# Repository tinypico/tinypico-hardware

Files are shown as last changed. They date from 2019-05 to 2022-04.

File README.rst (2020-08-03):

TinyPICO Hardware
=================

In this repository you'll find Eagle 9.x design files and gerbers for the TinyPICO and any of the shields we design ourselves.

Gerber files are provided in 274X format.

As we release new shields and designed, we will add them here. 

Open Source License
-------------------

These files are released as open source under the CERN license. Please review the license before using these files in your own projects to understand your obligations.

TinyPICO Branding
-----------------
The name TinyPICO, logos and TinyPICO brand are owned by Unexpected Maker. If you would like to use the name in a project you are making that supports the TinyPICO hardware, please contact us and we'll be happy to talk to you about it.

Support Unexpected Maker
------------------------

We love designing, making and releasing our projects as open source. We do it because we believe it’s important to share knowledge and give back to the community as many have done before us. It helps us all learn and grow.

That said, a lot of time, effort and finances have gone into designing and releasing these files, so please consider supporting us by backing TinyPICO on our Crowd Supply campaign:

https://www.crowdsupply.com/unexpected-maker/tinypico

Or by buying one of our products on tindie or our own shop:

https://www.tindie.com/stores/seonr/
https://unexpectedmaker.com/shop

Or by becoming a Patron:

https://www.patreon.com/unexpectedmaker

Unexpected Maker
===================
http://youtube.com/c/unexpectedmaker

http://twitter.com/unexpectedmaker

https://www.facebook.com/unexpectedmaker/

https://www.instagram.com/unexpectedmaker/

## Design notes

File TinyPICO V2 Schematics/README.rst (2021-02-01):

TinyPICO V2 Schematics
======================

PDF schematics for TinyPICO V2 for both USB-C and Micro-B boards

Unexpected Maker
===================

http://unexpectedmaker.com

http://youtube.com/c/unexpectedmaker

http://twitter.com/unexpectedmaker

https://www.facebook.com/unexpectedmaker/

https://www.instagram.com/unexpectedmaker/

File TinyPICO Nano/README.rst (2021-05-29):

TinyPICO NANO Footprints
===============================

In this folder you'll find various ECAD versions of the TinyPICO NANO footprint that you can use on your PCBs.

EasyEDA footprint kindly provided by Brian Lough ( https://www.youtube.com/channel/UCezJOfu7OtqGzd5xrP3q6WA )
https://easyeda.com/component/a96b3b5613954f7abe1ca396b1f5ce27

**TinyPICO_Nano KiCAD files** - KiCAD 6 (v5.99) & v5 Footprints & Symbols kindly provided by Mark Olsson ( https://github.com/k0d )

**TinyPICO_Nano.Library.IntLib** - Altium foorprint kindly provided by Ketan Desai ( https://twitter.com/ketszim )

Diptrace ASCII files kindly provided by airheadbit

For more information about TinyPICO & TinyPICO NANO, please visit
https://www.tinypico.com/tinypico-nano

Open Source License
-------------------

These files are released as open source under the CERN license. Please review the license before using these files in your own projects to understand your obligations.

TinyPICO Branding
-----------------
The names TinyPICO, TinyPICO logos and TinyPICO brand are owned by Unexpected Maker. If you would like to use the name in a project you are making that supports the TinyPICO hardware, please contact us and we'll be happy to talk to you about it.

Unexpected Maker
===================

http://unexpectedmaker.com

http://youtube.com/c/unexpectedmaker

https://www.patreon.com/unexpectedmaker

http://twitter.com/unexpectedmaker

https://www.facebook.com/unexpectedmaker/

https://www.instagram.com/unexpectedmaker/

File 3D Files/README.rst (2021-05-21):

TinyPICO STL & STEP Files
==================

STL & STEP files for the TinyPICO family of boards

Right now I only have the TinyPICO USB-C version and the TinyPICO NANO versions up, but I'm working on the Micro-B version and will upload it soon.

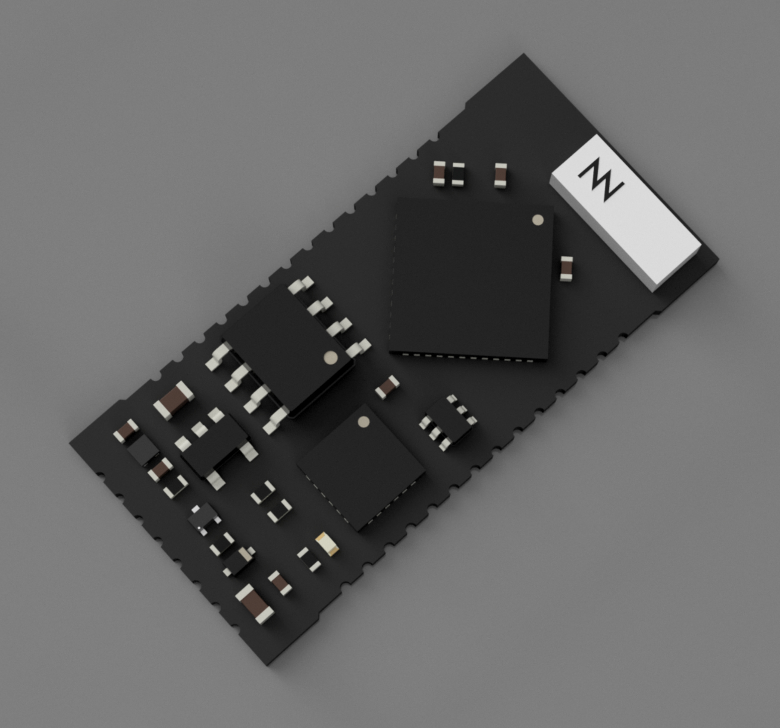
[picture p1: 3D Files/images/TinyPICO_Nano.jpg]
TinyPICO Nano STEP example


Unexpected Maker
===================

http://unexpectedmaker.com

http://youtube.com/c/unexpectedmaker

https://www.patreon.com/unexpectedmaker

http://twitter.com/unexpectedmaker

https://www.facebook.com/unexpectedmaker/

https://www.instagram.com/unexpectedmaker/

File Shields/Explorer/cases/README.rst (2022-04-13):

Explorer Shield 3D Cases
========================

In this repository you'll find the STL files for a slim and beefy case for your Explorer Shield

Support Unexpected Maker
------------------------

Please consider supporting me by purchasing one of my products on tindie or our own shop:

https://www.tindie.com/stores/seonr/
https://unexpectedmaker.com/shop

Or by becoming a Patron:

https://www.patreon.com/unexpectedmaker

Unexpected Maker
===================
http://youtube.com/c/unexpectedmaker

http://twitter.com/unexpectedmaker

https://www.facebook.com/unexpectedmaker/

https://www.instagram.com/unexpectedmaker/

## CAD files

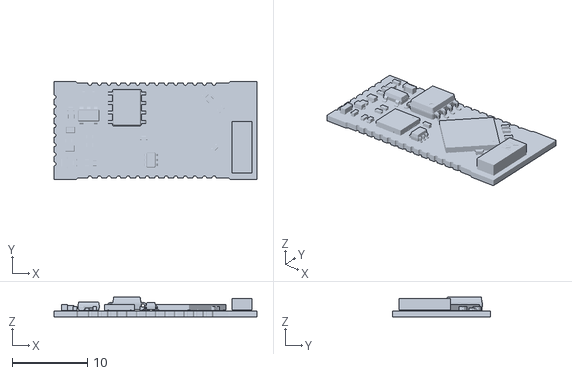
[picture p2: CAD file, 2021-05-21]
3D Files/TinyPICO Nano.stl
27.0 x 13.0 x 2.60

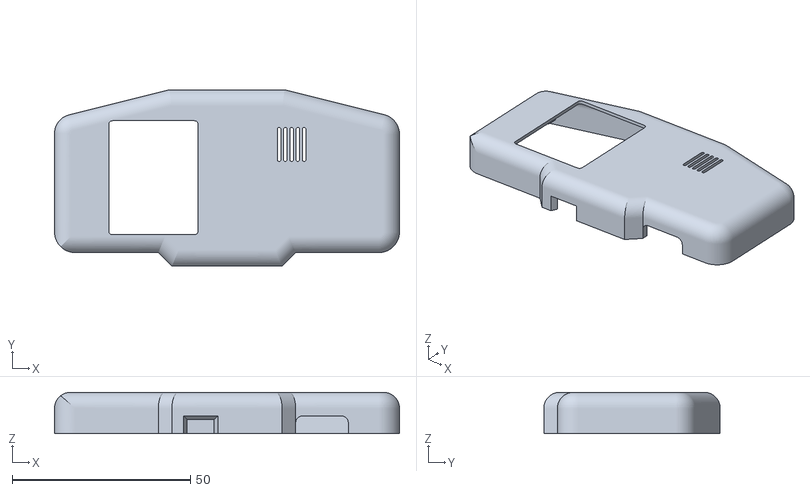
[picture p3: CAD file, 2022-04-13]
Shields/Explorer/cases/Explorer_Case_Slim.stl
96.7 x 49.5 x 11.6

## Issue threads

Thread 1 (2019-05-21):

Please consider maintaining "official" KiCAD footprint and symbol libaries.

sonopard, 2019-05-21:
Those things are needlessly hard to search for by with too many projects. Your chance to be better!

For now, I made this. https://github.com/sonopard/tinypico-kicad-footprint

UnexpectedMaker, 2019-05-24:
I don't use KiCAD so I won't be supplying footprints and design files, but I made the project is open source so others can contribute. So feel free to fork the project and submit pull requests for any KiCAD files you make and I can add them to the main repo.

Closed 2019-09-20.

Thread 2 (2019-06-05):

Eagle and Gerbers do not match

fcapano, 2019-06-05:
I've noticed some differences between the included gerber files and the Eagle project files.

For instance, the PSRAM' silkscreen is labeled "LY68L6400SLIT" in Eagle but simply "PSRAM" in the included gerbers.
Could you update the Eagle project so we are sure we're not missing any other more important change?

Thanks!

UnexpectedMaker, 2019-06-05:
Files have been updated, cheers.

Closed 2019-06-05.

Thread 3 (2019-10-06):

How are the values of L1, C4 and C5 decided?

dataplayer12, 2019-10-06:
Hi, I am wondering how you decided to use the values of L1 (7.5 nH), C4 (1.5 pF) and C5 (0.75 pF) for use with the antenna? The datasheet for the ESP32-Pico-D4, these values are different. Which value of these three would the performance be most sensitive to?

UnexpectedMaker, 2019-10-06:
The values on a matching network are specific to the exact board and layout its on. The values on the PicoKit are ONLY for the PicoKit - the values for the TinyPICO are ONLY for the TinyPICO.

Everything about the components on the board, their positions are orientations, the size of the board, number of layers, power and gnd copper pours, type of antenna, orientation of antenna, what other metal is near it.. it all changes the RF characteristics of the board.

The values on the TinyPICO are based on having it professionally matched by an RF expert.

Sounds like you need to do lots of reading up about RF and matching networks :)

dataplayer12, 2019-10-06:
Thanks a lot. I would really appreciate any pointers to reading material.

nevercast, 2019-10-07:
@dataplayer12 We do a bit of RF tuning at work, and what I have found is that, provided the antenna is 50ohms matched, you can usually put a 0ohm resistor across the series element (the series element on this particular board is C5, the element that is in series with the antenna line).

@UnexpectedMaker is correct that everything will change the performance of your antenna, and usually its best to tune it for its normal condition. For example, the TinyPICO probably spends most its time in a breadboard, so perhaps that would be the best situation to tune the antenna.

For your own board, it might usually be inside a chassis, and if its a handheld device, maybe it spends a lot of time in someones hands. So perhaps its best to tune it for that.

The fact is, your tuning will always be influenced by the environment and its not going to be perfect when its being used if that situation differs from when it was tuned in a lab. What advice I can give is that, if you're unable to follow recommended layout guidlines set out by the antenna you're using (such as shape and size of copper fills, and the proximity to other components), you might want to consider getting it tuned. If however, you have a very short trace from antenna port on the ESP32 to antenna on your board, you're probably fine putting a 0ohm series element in there, since the antenna should be already pretty close to tuned.

If you find the need to properly tune your antenna then I suggest buying a VNA, since unless you have a friend that will do the tuning for free, hiring an RF engineer with the equipment can be very experience. We use a miniVNA at my place of work and it does the job.

One extra point, when tuning, we usually put the tuned frequency at the left hand side -3dB point, so that the tuned frequency is slightly higher than ideal. That's because we suspect the device to be loaded by its surroundings and that will pull the frequency down to its ideal point.

I'd be happy to discuss this sometime if you want more information, find me on Twitter https://twitter.com/NvrCast

dataplayer12, 2019-10-07:
Thanks. Your explanation is very helpful. That explains why in some boards, people have left out the values of parallel elements. There may be no need to use them for most applications. I am curious as to why a 0 ohm series element is necessary. After all it is 0 ohm and as far as I understand, electrically it does nothing.

UnexpectedMaker, 2019-10-07:
The 0 ohm bridges he pads... otherwise there is a short between the ESP32 and the Antenna

dataplayer12, 2019-10-07:
Yes, I understand that, but could you not eliminate this part entirely and just have a wire in place of the pads.

nevercast, 2019-10-07:
> and as far as I understand, electrically it does nothing.
Correct. As @UnexpectedMaker pointed out, without briding the gap, the antenna and ESP32 are not connected. So you place a 0Ohm component in what would be C5 for the TinyPICO and that at least connects the Antenna to the ESP32 antenna port.

UnexpectedMaker, 2019-10-07:
Sure, you could just put a trace instead of the pads, but then how do you tune it with parts? The pads are there so you (if you get the expertise) or someone else can tune it... if you don't care about good quality RF, or even more, if you don't care that the implementation of your antenna could be reflecting, causing unwanted heat and power drain, then sure.. don't put any matching network, and just stick an antenna on there :)

UnexpectedMaker, 2019-10-07:
Unfortunately, RF is complicated, and it's not a "one size fits all" - every board design that implements an antenna should be tested to *at least* ensure the board is performant and doesn't have adverse effects from heat or power.

Ultimately, if you are making a hobby project for yourself, and putting an antenna on your board gives you the wifi quality you need, you can avoid getting it matched.., but if you are making something for others to use, then a properly matched network is the right thing to do.

dataplayer12, 2019-10-07:
Your advice makes a lot of sense. Since this is my first board, I will not tune it and see how it works. Thanks, you have been a great help!

niemeyer, 2021-02-06:
Here we are in 2021, on a Saturday, and this is still an interesting thread. Kudos to all commenters.

Montvydas, 2021-04-25:
I know the issue was closed, but since the TinyPico changed the RF design slightly, I was wondering, why was the matching network removed from V2 design completely as can be seen [here](https://github.com/tinypico/tinypico-hardware/blob/master/TinyPICO%20V2%20Schematics/TinyPICO_V2_C2_Schematic.pdf)? This surprised me since the previous design later added an identical 3D antenna, thus I was expecting to see a similar matching system..

matt-42, 2022-01-07:
> I know the issue was closed, but since the TinyPico changed the RF design slightly, I was wondering, why was the matching network removed from V2 design completely as can be seen [here](https://github.com/tinypico/tinypico-hardware/blob/master/TinyPICO%20V2%20Schematics/TinyPICO_V2_C2_Schematic.pdf)? This surprised me since the previous design later added an identical 3D antenna, thus I was expecting to see a similar matching system..
>
> Edit: So it seems the matching network should be removed if the transmission line length is smaller than 5mm (1/10 of wavelength), I guess that might be the case then on V2...

That would be great where did you find this info? I found another ESP32 board without matching circuit: https://github.com/TobleMiner/ESP32-Devkit-Type-C/issues/3

Montvydas, 2022-01-13:
> That would be great where did you find this info? I found another ESP32 board without matching circuit: [TobleMiner/ESP32-Devkit-Type-C#3](https://github.com/TobleMiner/ESP32-Devkit-Type-C/issues/3)

Well, the bits of information are scattered there and there, but if you watch [this talk](https://www.youtube.com/watch?v=ZYUYOXmo9UU), or at least the bit starting at 38:30, it talks about when to care about the line lengths. In the video they used 1/12 of the wavelength, which is more precise, but 1/10 is easier to calculte, that's why it's usually used... So a rule of thumb! Basically a typical PCB dielectric (FR-4) has a relative permittivity of ~4.5. If  it's an inner layer trace, then the refractive index is 2.12 (square root of permittivity). On the outer layer, it is a combination of both air and the PCB dielectric, thus the relative permittivity of ~3.5, then the refractive index is 1.87. Thus, depending on the scenario the velocity drops by a factor of 2.12 (inner) / 1.87 (outer), which changes the wavelength of the 2.45GHz signal to 57.7mm / 65.5mm (wavelength = speed / freq). 1/12th of that is 4.8mm / 5.45mm, meaning if the transmission line is longer than that, then a matched network needs to be added. This is theoretical though, since any components on the board and the added device case (even if made of plastic) will affect the antenna and thus it will require rematching.. However with a case on is added the BLE will still work, it will simply add losses and thus battery will be drained somewhat faster if you want to keep the same signal strength.

Anyway, an easy thing to do is to add a pi-network with a 10pF capacitor shorting the MCU and the antenna. At 2.45GHz 10pF is somewhat close to 0 Ohm impedance and thus it will not change anything. However if you later decide that you want you device matched you can send it to a specialised service and they will decide what the pi-network components should be. Note that a 0 Ohm resistor will not work as 0 Ohm impedance at 2.45 GHz, since it has inductance, thus better use the 10pF capacitor (it is worth checking manufacturer graphs for their capacitors as they got impedance vs frequency graphs for various capacitor sizes and packages.. thus helping to decide for the best value, just 10pF is usually somewhat OK). Hope that helped!

Montvydas, 2022-01-14:
Regarding TobleMiner/ESP32-Devkit-Type-C#3, if you use a PCB antenna, then you can avoid using a matching network by firstly making the antenna tail longer than needing. Then during the matching process you can cut the tail bit-by-bit until you establish a matched network. This type of process changes the antenna built-in impedance (combination of capacitance and inductance) by physically altering the antenna rather than introducing extra components. That's one of the benefits for using a PCB antenna in this case, but you would still need a VNA (or can get a nanoVNA for under £50 on Aliexpress). I think I learnt this from Robert Feranec video, where they discussed antennas, but cannot be 100% sure now, it was some time ago now...

matt-42, 2022-02-08:
Thanks @Montvydas for all the explanations :)

Closed 2019-10-07.

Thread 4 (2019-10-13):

Gerbers_274X TinyPICO.sol

SZ-MXK, 2019-10-13:
Hi,
The Gerbers file is wrong.

UnexpectedMaker, 2019-10-13:
Sorry, but the gerber is correct. These are the production gerbers that I shipped thousands of boards with.

Closed 2019-10-13.

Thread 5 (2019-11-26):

how much current will the gpio35 draw?

dukeduck1984, 2019-11-26:
when the battery voltage ADC is not in use, how much current, if any, will the gpio35 draw?

Thanks,
Kaiyuan

nevercast, 2019-11-26:
GPIO35 is an input only pin and has no hardware drivers. Therefore the pins should follow nominal leakage characteristics when not being sampled. Therefore I would expect 50nA according to the input current specified here: https://www.espressif.com/sites/default/files/documentation/esp32_datasheet_en.pdf#page=41 and here https://www.espressif.com/sites/default/files/documentation/esp32-pico-d4_datasheet_en.pdf#page=15

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

nevercast, 2019-11-26:
Looking at the schematic https://github.com/tinypico/tinypico-hardware/blob/master/TinyPICO%20Release%20P3/TinyPICO_Schematic.pdf

The divider is always enabled when on battery and sends the battery to ground through about 600kOhm which is about 6 microamps at 3.7V. You can probably increase the resistor values and keep their ratio if 6 microamps is too much for you.

UnexpectedMaker, 2019-11-26:
The divider is always on when the board is powered, even if no battery is present, as the PMIC can't tell the different between no battery and a full battery, so still tries to charge, so VBAT always has voltage, so the divider is always sucking current.

But as Josh pointed out it's low uA... I'd not increase the resistors unless you don't want to be able to read the voltage accurately, as higher value resistors will just increase their susceptibility to noise, decreasing the ADC's accuracy.

So if you don't need to read the voltage, removing one of the divider resistors means no current use at all, but if you do want to read the voltage, ultimately, it's not costing much.

The TinyPICO deep sleeps at 18uA or less.

Closed 2020-03-17.

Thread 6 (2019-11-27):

Add ov2460 camera

dontsovcmc, 2019-11-27:
Thanks a lot for you tiny board!
It's what I need. How do you think, is it hard to add ov2460 2MP camera module to the board? ESP32-CAM board is rather popular, but isn't power safety and big. I can help, if possible.

UnexpectedMaker, 2020-03-17:
Feel free to make an OV2460 shield for the TinyPICO and contribute it back to the project, as it is open source after all.

Closed 2020-03-17.

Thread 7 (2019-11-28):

Where can I download a 3D Model?

Pro, 2019-11-28:
We would need the 3D Model of the TinyPico for building a Case and visualizing the board on it.

Could you add the model to the git repo (in the ideal case as STEP file)? Or is it available somewhere else?

UnexpectedMaker, 2019-11-28:
Sorry, there is no 3D model for the TinyPICO.

Seon Rozenblum | Unexpected Maker
http://unexpectedmaker.com <http://unexpectedmaker.com/>

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

Pro, 2019-11-28:
Bad news, but thanks anyways!

taf2, 2021-12-15:
I found this one which is pretty good https://grabcad.com/library/tinypico-esp32-1  it is an older model but I've been using it with some success

UnexpectedMaker, 2021-12-15:
Official models are all available here.... :)
https://github.com/tinypico/tinypico-hardware/tree/master/3D%20Files

Closed 2019-11-28.

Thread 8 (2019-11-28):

External 5V Power supply and USB 5V at the same time?

Pro, 2019-11-28:
I have a setup where the 5V Pin is connected to an external power supply.

My question:
Is it safe to plug in the USB Cable with its own 5V Power Supply while there's still 5V coming through the 5V Pin?

Use Case is that I need to re-flash it while the external power supply is on, or I want to open the monitoring through USB.

Thanks!

Pro, 2019-11-28:
I already checked the board itself and saw that the 5V goes to a Chip with labeling "65b902". I couldn't find out which chip it is.

UnexpectedMaker, 2019-11-28:
No, there is no reverse USB protection, so you may backfeed power and damage your host USB port. Only way is to ensure the power going into the 5V pin is lower than the 5V from the USB, but even then, its not recommended.

Also, this repo is not for TinyPICO support, sorry...  Please join my discord server for support Q's.
https://discord.gg/xAHpApP

Thanks.

Pro, 2019-11-28:
Ok, sorry for spamming here. Will use the Discord Server! Thanks anyway for answering!

Closed 2019-11-28.

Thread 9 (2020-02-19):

Low-Battery / Over discharge

CrispinP, 2020-02-19:
What stops over discharge of the battery?

I can't see anything in the schematic that would handle this.

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
The ESP can operate down to 2.2V. With the LDO drop of 190mV that would pull the battery down to 2.3/2.4V before it would get flaky. A bit low for a li-ion battery.

Have I missed something?

nevercast, 2020-02-19:
For what it's worth, the ESP32-PICO can only work down to 2.7V due to the internal flash being a 3v3 device. You will get flash errors lower than 2.7V

UnexpectedMaker, 2020-02-19:
Yup, you need to use protected LiPos. The ones with the yellow on the top.
This really isn't a TinyPICO github issue, and is more a question for Discord :)

CrispinP, 2020-02-19:
ah ok. Thanks.
So I'm not reading it wrong.

(Agreed on the last point 😄 )

Closed 2020-02-19.

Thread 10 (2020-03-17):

Req: Missing part libraries

henrygab, 2020-03-17:
Just found and picked up my first TinyPICO ... very impressive form factor.

I went ahead and loaded the board & schematics in Fusion 360 (which now has the functionality of Eagle built-in).  The problem is, many of the parts used reference libraries that are not public.

Could you please do one of the following two things?

1. make the following libraries, which contain parts used by the TinyPICO, available in the git repo?
  * cmonr_standardparts
  * CP2104
  * microbuilder
  * NCP170AMX300TCG
  * Philbywhizz
  * supply1
  * UnexpectedMaker

2. Alternatively, can you put all the parts used for this board into a single library, and make it a "managed" library in Eagle? This would allow it to be downloaded automatically by Eagle / Fusion360 users, including getting updates if anything changes.

Having the libraries for the parts is the first step to enabling full 3D models in Fusion360.  Having the 3D model makes it **_really_** easy for makers to create custom enclosures, using any output supported by Fusion360 (e.g., 3D-printing, laser-cut acrylic, CNC, etc.).  The 3D model it makes is already really good, but it can't show the usb connector, and the boxes are wrong-sized for other parts.  Still, it's already really close!

The only remaining step then would be to ensure the parts have the 3D models ... which is itself a zero-cost service (for end users).  Mouser, for example, has some relationship with [LibraryLoader](https://www.samacsys.com/library-loader-help/), and they turnaround simple new requests (e.g., common chip packages) in ~48 hours.

Thanks!

UnexpectedMaker, 2020-03-17:
Hi Henry,

I didn't supply a TinyPICO library because it's really not needed due to the way Eagle works.

All of the data you need for each part on the board is in the board file, so you can easily and quickly make your own library of the parts of you want to go down the road of attaching 3D models to the components.

Create a library, open it in the editor, and then right click on the parts you want to add, and copy the device to the library. From there, you can assign 3D models if you choose.

As the project is open source, what you are asking for seems like a perfect candidate for what you (or others could make) and then contribute back to the project :)

Cheers,
Seon

henrygab, 2020-03-18:
Hi @UnexpectedMaker ,

Thanks for the quick response.  I am willing to do this, and submit a PR.  The steps for doing this are not obvious.

<details><summary>Parts list context menu fails...</summary><P>

However, I'm not entirely clear how to copy a device that has no backing library from and existing brd/sch pair.

My steps to try:
1. Create new user library
2. Open the TinyPICO.sch schematic in Eagle
3. Select `Design Manager` super-tab
4. Select `Browser` to see the parts list
5. Click on header `Device` to sort by device name
6. Right-click on part `IC2G$1`, the CP2104 USB-to-Serial chip
  a. Clicking `Package` results in error: `Part 'IC2G$1' not found!`
  b. Clicking either `Open Symbol` or `Open Device` results in error: `Library CP2104.lbr was not found in current library path(s). Please adjust the library paths or download or export the drawing libraries first!`

</details>
<details><summary>Export?</summary><P>

I am now trying File->Export, to dump all the parts used into a new library.  This seems to generate a large script, and runs the script to add parts to the new library ... with all the performance that suggests.  I'm waiting for this to finish.
</details>

Is this export option the start of the path you were suggesting, or did you have another alternative in mind?  I couldn't find a way to just right-click on a part to be able to add it to a new library....

UnexpectedMaker, 2020-03-18:
1. Create and open a new library.
2. Import & open TinyPICO schematic
3. Right click on a symbol in the actual schematic
3. Select "Copy device to library" - will be greyed out if the library is not open.
4. Repeat for all components, then save the library.
5. Win!

This is the Eagle workflow that also works in Fusion360

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

henrygab, 2020-03-18:
Awesome!  Thanks for the pointers.  I'll see what I can put together!

henrygab, 2020-03-18:
Update:  Any efficient use of Eagle appears beyond my ken.  I've either given up, or put this on a backburner for now.

Closed 2020-03-18.

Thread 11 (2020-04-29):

Schematic for RGB IPS Display Shield

patfelst, 2020-04-29:
Hi Seon, is it possible to publish the schematic for your RGB IPS Display Shield please?

Thanks!

mcauser, 2020-06-25:
Hi @patfelst I don't have the schematics, but I know the pinout:

|TinyPICO|IPS Display|
|-|-|
|n/c|MISO|
|GPIO23|MOSI|
|GPIO18|SCLK|
|GPIO5|CS|
|GPIO15|DC|
|GPIO14|Backlight|
|n/c|RST|
|3V3|VCC|
|GND|GND|

No MISO means you can only write data to the display, you can't read any data back.

UnexpectedMaker, 2020-06-25:
Thanks for the push @patfelst ;)
https://github.com/tinypico/tinypico-hardware/tree/master/Shields/IPS%20Colour%20Display

patfelst, 2020-06-25:
Thanks again

Closed 2020-06-25.

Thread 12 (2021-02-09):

No schematic for the tinypico nano

Leviathan220, 2021-02-09:
I am trying to design a board in kicad using the tiny pico nano. I have installed the kicad footprint but, where is the schematic. I can make one from scratch using the pdf if I need to. Please let me know if you would like and I will attach a copy unless you have one I can use.

UnexpectedMaker, 2021-02-16:
KiCAD Symbol has been added, cheers :)

Closed 2021-02-16.

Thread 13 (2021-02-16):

Honored but not sure if it was an accident.

Leviathan220, 2021-02-16:
I hopped on today to download the kicad symbol. I haven't tried it yet however, when going to download the files I noticed I had permission to edit the repo. I figured I would bring it to your attention as I wasn't sure if you did so on accident. I'm still waiting on my recent order to arrive but, I'm honored you'd trust me with permissions to your repo.

nevercast, 2021-03-20:
Your user doesn't say contributor or maintainer. Are you sure you have writes to modify this repo and it's not GitHub abstracting away a fork of this repo ?

Closed 2021-07-16.

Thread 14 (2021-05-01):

STL files

Death111, 2021-05-01:
Hey,
I wanted to download TinyPICO_V2_USBC STL files https://github.com/tinypico/tinypico-hardware/tree/master/STL%20Files but only .step file is available. Do you also have STL files?

I want to use it as reference for 3d modeling case and to not have a tool supporting .step files.

Thanks
Death

UnexpectedMaker, 2021-05-14:
Once I `finally` get the step modules finished, I'll see if I can export STL's as well.

Death111, 2021-06-12:
I notice you were able to export the STL's :) Thanks @UnexpectedMaker

~ https://github.com/tinypico/tinypico-hardware/tree/master/3D%20Files

Closed 2021-06-12.

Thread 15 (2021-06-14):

C23 is a duplicate of C1?

FreezeS, 2021-06-14:
Hi Seon,

I believe this was accidental but if you did it on purpose then what's the purpose?
Is the capacitance/inductance of the wire between the reset button and the reset pin so high that it needs two capacitors?

UnexpectedMaker, 2021-06-14:
It’s not accidental. Both caps were included on purpose. C23 sits at the auto reset circuit.

Closed 2021-07-11.

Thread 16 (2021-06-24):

tinypico board layout

bilaljo, 2021-06-24:
I would like change out the prog resistor R3 against another (to change the battery current properly for my LiPo). Since I have only the schematic (and real board) it is hard to figure out which one is the correct one. I could only guess, which is quite unsafe.
Could you push an layout file of tiny pico (nano) as well?
Thanks.

UnexpectedMaker, 2021-06-24:
Sorry, which board are you asking about the VBAT Prog resistor for? The TinyPICO or the TinyPICO Nano?

bilaljo, 2021-06-24:
Sorry vergot to mention. The TinyPICO Nano.

UnexpectedMaker, 2021-06-24:
I've highlighted the resistor with a blue outline.

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

bilaljo, 2021-06-24:
Great, that's what I was searching for! Thank you very much.

UnexpectedMaker, 2021-06-24:
Nps!

Closed 2021-06-24.

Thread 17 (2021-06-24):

Casing of R3 PROG (Tiny PICO Nano)

bilaljo, 2021-06-24:
Has the casing of R3 PROG Resistor from Tiny PICO Nano a 0402 casing? The size looks so.

UnexpectedMaker, 2021-06-24:
Yes, it's an 0402 3.3K resistor.

bilaljo, 2021-06-24:
Thank you!

Closed 2021-06-24.

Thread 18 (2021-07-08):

Other I2C pin than IO21 and IO22

bilaljo, 2021-07-08:
It is possible to use other pin than IO21 and IO22 for I2C? They are marked as I2C pins on the tinpy pico pinout which makes me quite unsure.

UnexpectedMaker, 2021-07-08:
You can initialise I2C with any pins, but 21,22 will give you hardware I2C, where other pins will be software I2C.

bilaljo, 2021-07-08:
Thank you for your answer. Is that a tiny pico specific feature? Since I found this post on the esp32 forum:

"Yes, the digital portion has two hardware I2C modules. You don't see the pins for it in the pinout because they're conencted to the GPIO mux and you can connect them to any of the (output-capable) GPIOs."

https://esp32.com/viewtopic.php?t=215

UnexpectedMaker, 2021-07-08:
TinyPICO is an ESP32 and can do whatever an ESP32 can do. Some pins will give you hardware, some software I2C depending on which you use.

The ESP32-PICO-D4 datasheet is the best place to look.

Closed 2021-07-16.

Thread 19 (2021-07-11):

Sensing when USB power is present on V1 boards

Paraphraser, 2021-07-11:
I have some TinyPico V1 but an application where they will mostly be getting power via USB but I would like to be able to sense when USB power goes away and the battery takes over.

In comparing the V1 P3 and V2 C2 schematics, it looks like the V1 boards can't do that. True? Or am I misreading the purpose of GPIO9? Is there a workaround?

I'm happy to order some V2 if need be. I just didn't want to do it unnecessarily.

UnexpectedMaker, 2021-07-11:
That's correct. V1 doesn't have this capability on board. It's a V2 only feature. You can add this yourself by connecting a voltage divider between the 5V pin and GND and connecting the middle of it to an IO on the TP and reading if it is high or low.

Closed 2021-07-16.

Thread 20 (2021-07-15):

Unable to flash tiny pico nano

bilaljo, 2021-07-15:
Is there anything to consider when flashing a self-designed board with a tiny pico nano?
I am using a micro usb B as port and UART is working fine (since I am able to see the tiny pico nano as listed device) but I got always the error
"esp32 invalid head of packet"
I know thats for esp32 a well-known issue but all suggested solutions do not working (especially because they are only for pre-builded boards).

UnexpectedMaker, 2021-07-15:
Do you have anything connected to IO0, IO2, IO5 or IO12?
Can you share your schematic with me? You can email it to me if you don't want to post it here publicly.

All Nanos go through the testing twice. Once before being cleaned and once again after being cleaned, so all boards have successfully been flashed 2 times with MP and have had all of the tests run on them twice.

bilaljo, 2021-07-16:
Yes, I have IO12 connected to a device.

UnexpectedMaker, 2021-07-16:
IO12 is a strapping pin.  It needs to be untouched at boot, or at best, never pulled high during boot.
Check the PICO-D4 Datasheet for all scraping pins and what you can and can't do with them during boot up.

bilaljo, 2021-07-16:
Thank you very much. In fact it was a socket for a battery so only connecting + and - (without battery) while flashing solved it.
Oh I see I meant actually IO2 but I think same problem with IO2, right?

UnexpectedMaker, 2021-07-16:
Why are you connecting a battery to IO2? Never connect a power source to an IO pin.

bilaljo, 2021-07-16:
For watching the battery level since it has an ADC.
Oh is that a serious problem?

UnexpectedMaker, 2021-07-16:
So long as it’s going through a voltage divider it’s ok.

You should have nothing connected to any strapping pins at all that influence the state of them at boot time.

None of this is TinyPICO Nano related, so I’m going to close this as it’s not an issue.

Feel free to join my discord to ask questions there.

Closed 2021-07-16.

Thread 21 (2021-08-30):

Charging current resistor hint correction

Techspiring, 2021-08-30:
Hey mate,

I'm currently supporting a friend using the tiny pico.
The TPS4065 you're using is designed for charge-currents of 3 .. 600mA.
Charging at 1.000mA is not working properly, so the hint for the 1k0-Resistor in the schematic is a bit off.

Here is the product page if you want to check.
http://www.tp-asic.com/te_product_a/2009-05-20/2636.chtml

All the best :)

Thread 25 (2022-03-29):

Which contact is GPIO13?

CluckCluckChicken, 2022-03-29:
GPIO13 is used to toggle on/off the DotStar LED, but I need to use it for something else (it is HSPI MOSI and I have a screen that I want to run at a higher refresh rate). Where is the contact on the board so that I can desolder whatever is there and solder on something of my own?

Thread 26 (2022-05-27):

tinypico not upload program using platformio with micro USB

waqas-subhani, 2022-05-27:
kindly help, if anyone of can. thanks

A fatal error occurred: Failed to connect to ESP32: Wrong boot mode detected (0x13)! The chip needs to be in download mode.
For troubleshooting steps visit: https://docs.espressif.com/projects/esptool/en/latest/troubleshooting.html
*** [upload] Error 2

UnexpectedMaker, 2022-05-27:
Sorry, not the place to ask this - It sounds like a platformIO configuration issue. Please try my discord server, or the platformIO community.

Closed 2022-05-27.

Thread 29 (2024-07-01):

PCB Dimensions for footprint and Shield Ground

JL1946, 2024-07-01:
Hello...
I am making a Kicad footprint for the TinyPICO P3 Board... I am using the tinypico/tinypico-hardware/TinyPICO Release P3/Eagle/TinyPICO.brd to make the measurements using the built-in Kicad measuring tool... With the board placed such that the long-side is in the  y-direction and the short side in the x direction, the distance between the each pad in the y-direction is the standard 2.54 mm or .1 in... However, in the X direction I am measuring 15.2654 mm or 0.601 in between the pads (center-to-center)... Is this correct??? As for the size of the board (less critical), I am measuring the y-direction as 31.852 mm or 1.254 in. and 17.780 mm or  0.7 in.  Are these measurements in the ball-park???

I have included some jpg photos to show the orientation of the footprint...

One last thing... From the schematic, I saw that you tied the shield of the USB-C connector to the power/signal ground... I am incorporating your board onto another board which implements a separate trace for Earth-Ground which the usb-c cable shield routes to an Earth connection at the power supply... The design is using TVS diodes to transfer any ESD picked up by the sensors of the system to that Earth-Ground path... However, with Shield tied to the signal/power ground, it seems to me that any ESD would be routed to that ground as well... What is your opinion on this issue? Thanks for your timely response on the issues that I have outlined in this writeup...
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

UnexpectedMaker, 2024-07-01:
I guess all that really matters here is to have 32x18mm clearance for the board (maybe longer to ensure antenna clearance from other components on your carrier board) and the headers are 17.78m apart (7x 2.54mm header pin spacing).

With regards to the USB shielding being connected to GND, I'm not really sure how you have all of that connected as you mention another USB-Connector connected to your power supply?

Even without the TinyPICO USB Shield connected to the TinyPICO GND, you still have GND connected via the TP USB-C connector through the wires, so that is already going to connect to your "Earth GND" if you have them common - and I'm. not sure how it would work if they were not common - technically both could be the same value, but technically they could be quite different, and then you'd mess with the voltage rails on the TinyPICO.

I think what you need to do, is if you are connecting USB to the TinyPICO (I assume for flashing etc, but other times the power will come from your other supply?) then you should use a modified USB-C connector that has GND and maybe 5V cut so it only provides D+/D-.

The USB-C shield -> GND part really makes no difference here as You are connecting USB-C->GND anyway.

Without seeing your intended schematic or having a thorough understanding of what you are doing I can't really advise any best practice here, sorry.

JL1946, 2024-07-05:
Hi...
Thank you for your response... Please clear this up for me... I measured the distance between the headers to be 6 x 2.54 mm = 15.24 mm, not 7 x 2.54 = 17.78 mm... I measured the board width to be 17.78 mm which would make sense if you list the pcb as 18mm x 32mm...

Sorry to hound you, but I live in Canada and am ordering the TinyPICO V3 from the USA... My pcb's are being made in China... I don't want to make a mistake... thanks for understanding...

UnexpectedMaker, 2024-07-05:
Sorry, I don't understand the question, you don't measure between the headers, you measure from header to header, The headers are 17.78mm apart.

How much space you have between them is not a measurement I can give you, as it depend on how you mount the board to your carrier., What type of headers you use. Surface mount headers on your carrier will take more space then through hole.

JL1946, 2024-07-06:
I have included 3 photos to try to clarify my issue... The first is a picture of your board I want to use... the second is a jpeg of the motherboard I designed that shows the footprint placement of the TinyPICO P3 board that I want to buy from you... The third is a jpeg of the Top Copper Layer or TinyPICO.cmp file from your Github/.../TinyPICO Release P3/Gerbers_274X directory... This jpeg shows 3 pads marked "A", "B", and "C"... According to the Gerber Viewer that I am using, The x-y positions of the pads in mm (relative to 0,0 axis) are as follows:
"A" --> x:4.8885  y: 21.3444
"B" --> x:7.4285   y: 21.3444
"C" --> x:4.8885  y: 6.0790

When I do the math, I get the distance between Pads "A" and "B" to be 2.54 mm... The distance between Pads "A" and "C" to be 15.2654 mm which is very close to 6 times 2.54, NOT 7 times 2.54... The Gerber viewer I'm using can't be wrong or, otherwise the calculated distance between Pads "A" and "B" would be wrong...

I want to have my board manufactured but don't want to make a mistake and waste time and money... I hope that this clarifies the issue I'm having...

Also, If I purchase from your website:
( https://unexpectedmaker.com/shop.html#!/TinyPICO/p/577111313/category=154494282 ) Do you ship to Canada?

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

UnexpectedMaker, 2024-07-06:
Sorry, I miss understood what you were asking originally.

Here are the dimensions in an easy to understand way:
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

Yes, I ship all over the world from my website :)

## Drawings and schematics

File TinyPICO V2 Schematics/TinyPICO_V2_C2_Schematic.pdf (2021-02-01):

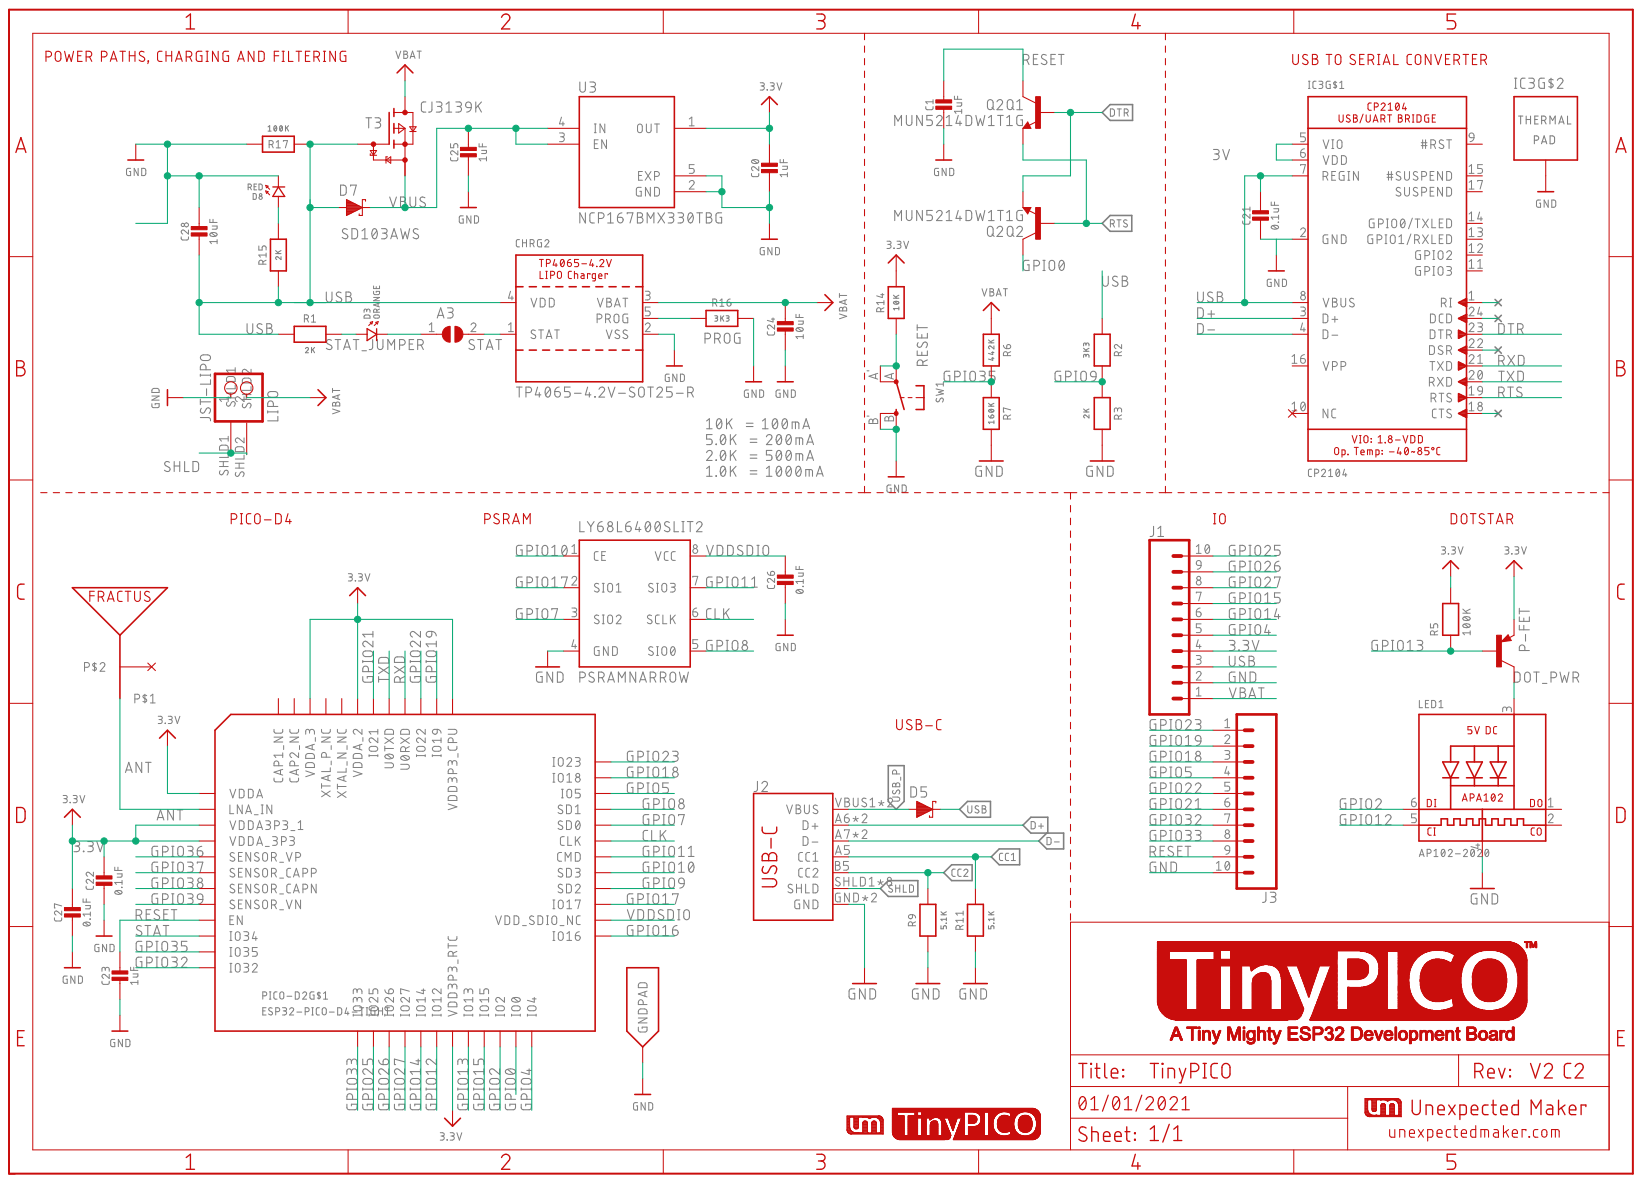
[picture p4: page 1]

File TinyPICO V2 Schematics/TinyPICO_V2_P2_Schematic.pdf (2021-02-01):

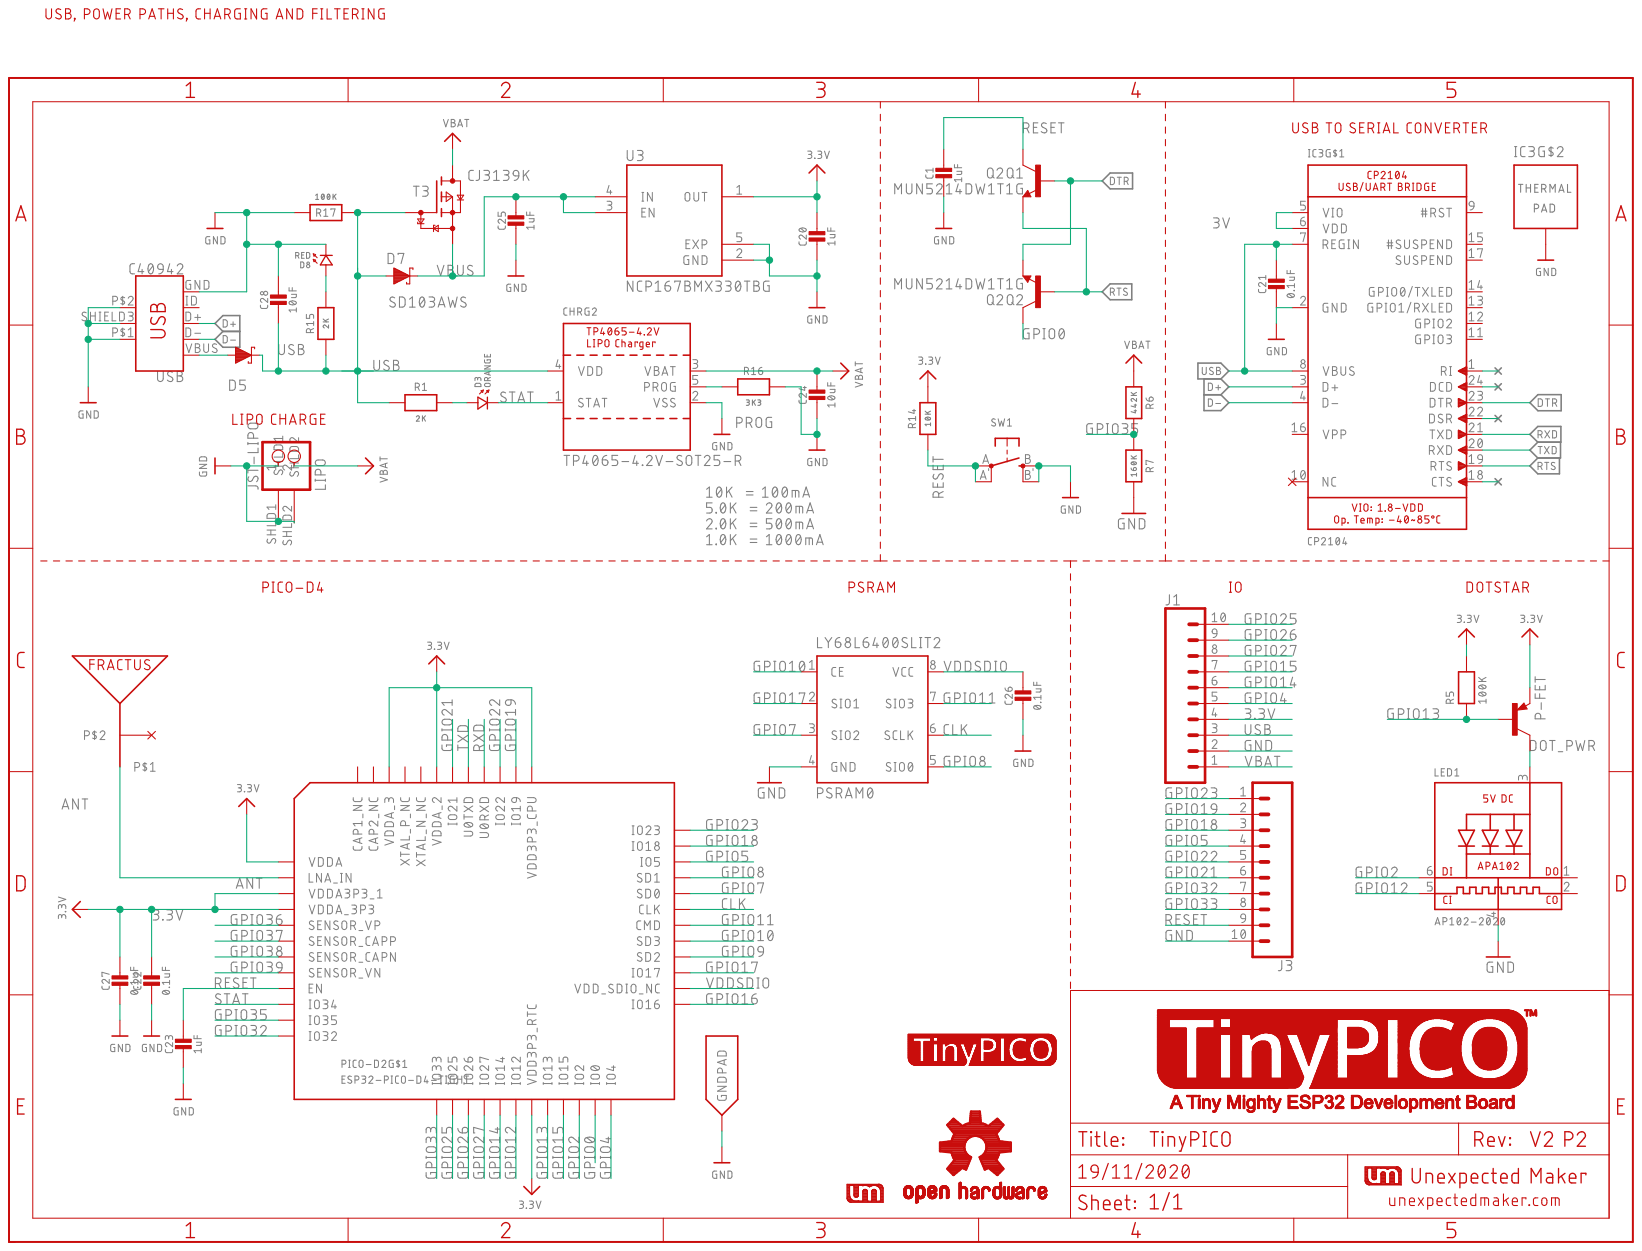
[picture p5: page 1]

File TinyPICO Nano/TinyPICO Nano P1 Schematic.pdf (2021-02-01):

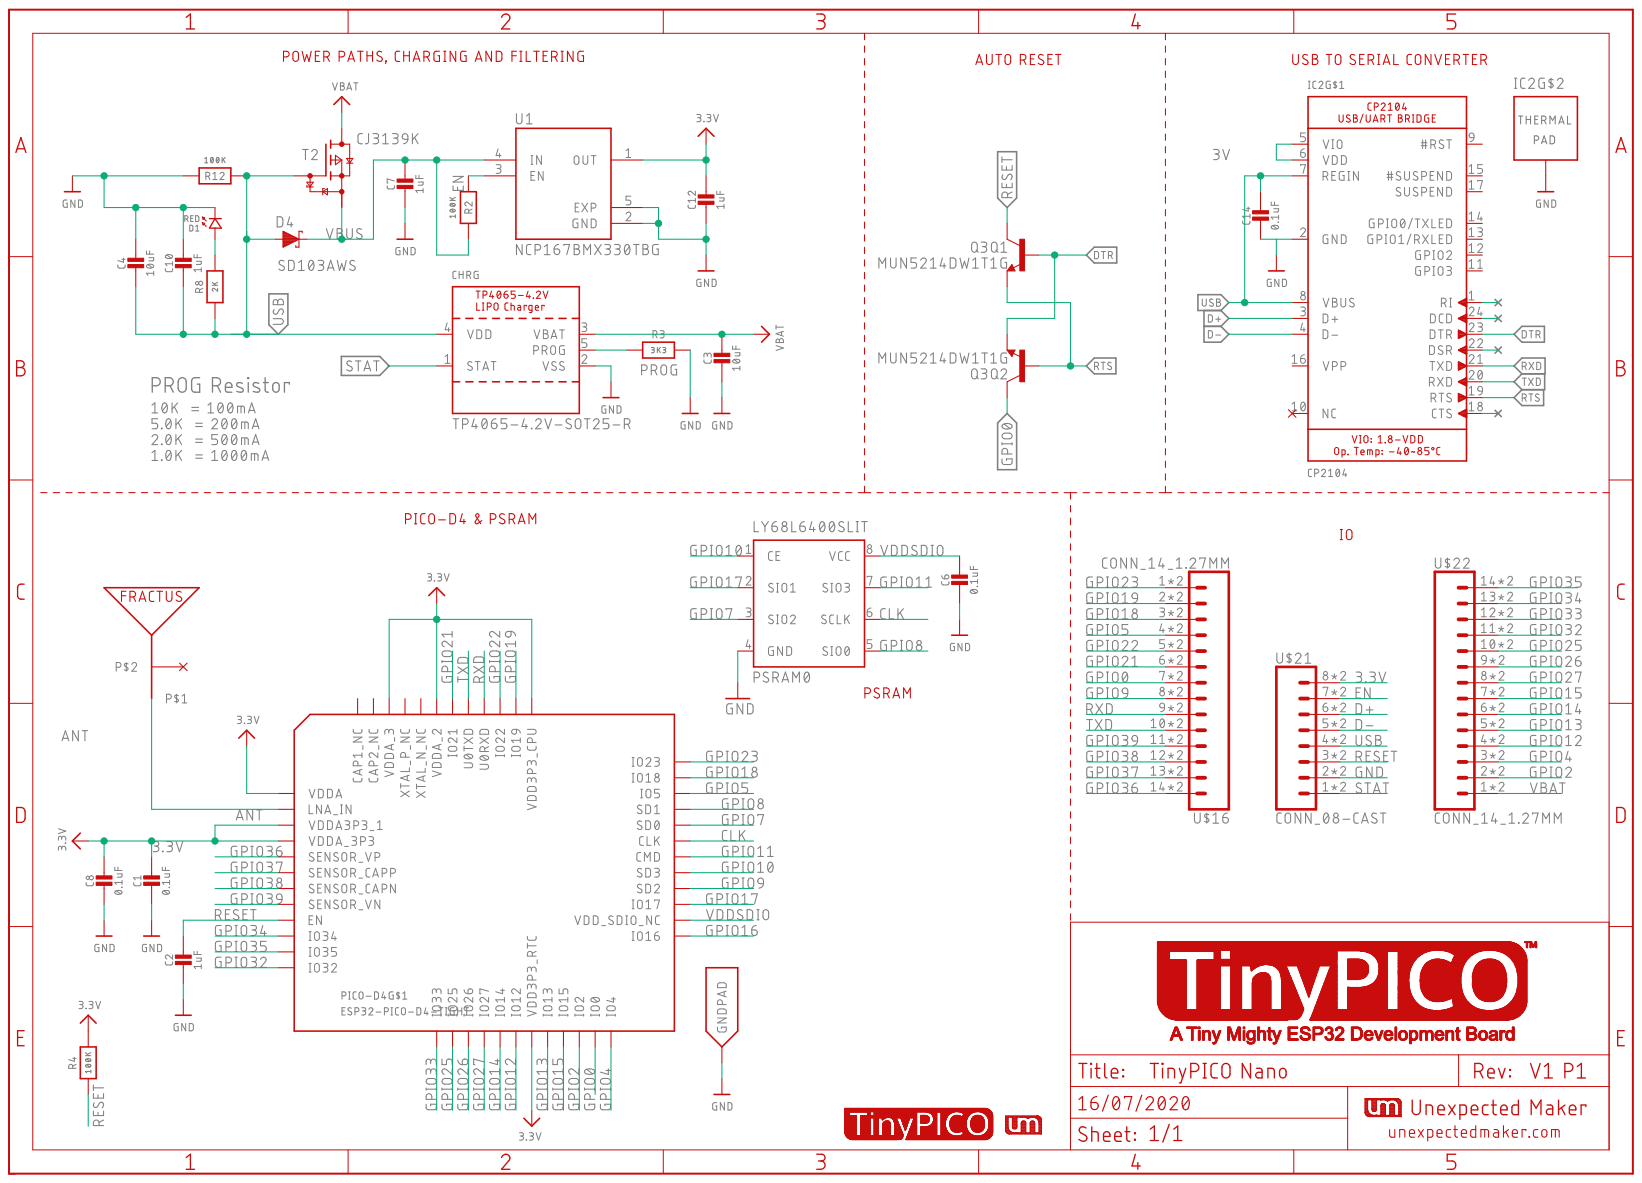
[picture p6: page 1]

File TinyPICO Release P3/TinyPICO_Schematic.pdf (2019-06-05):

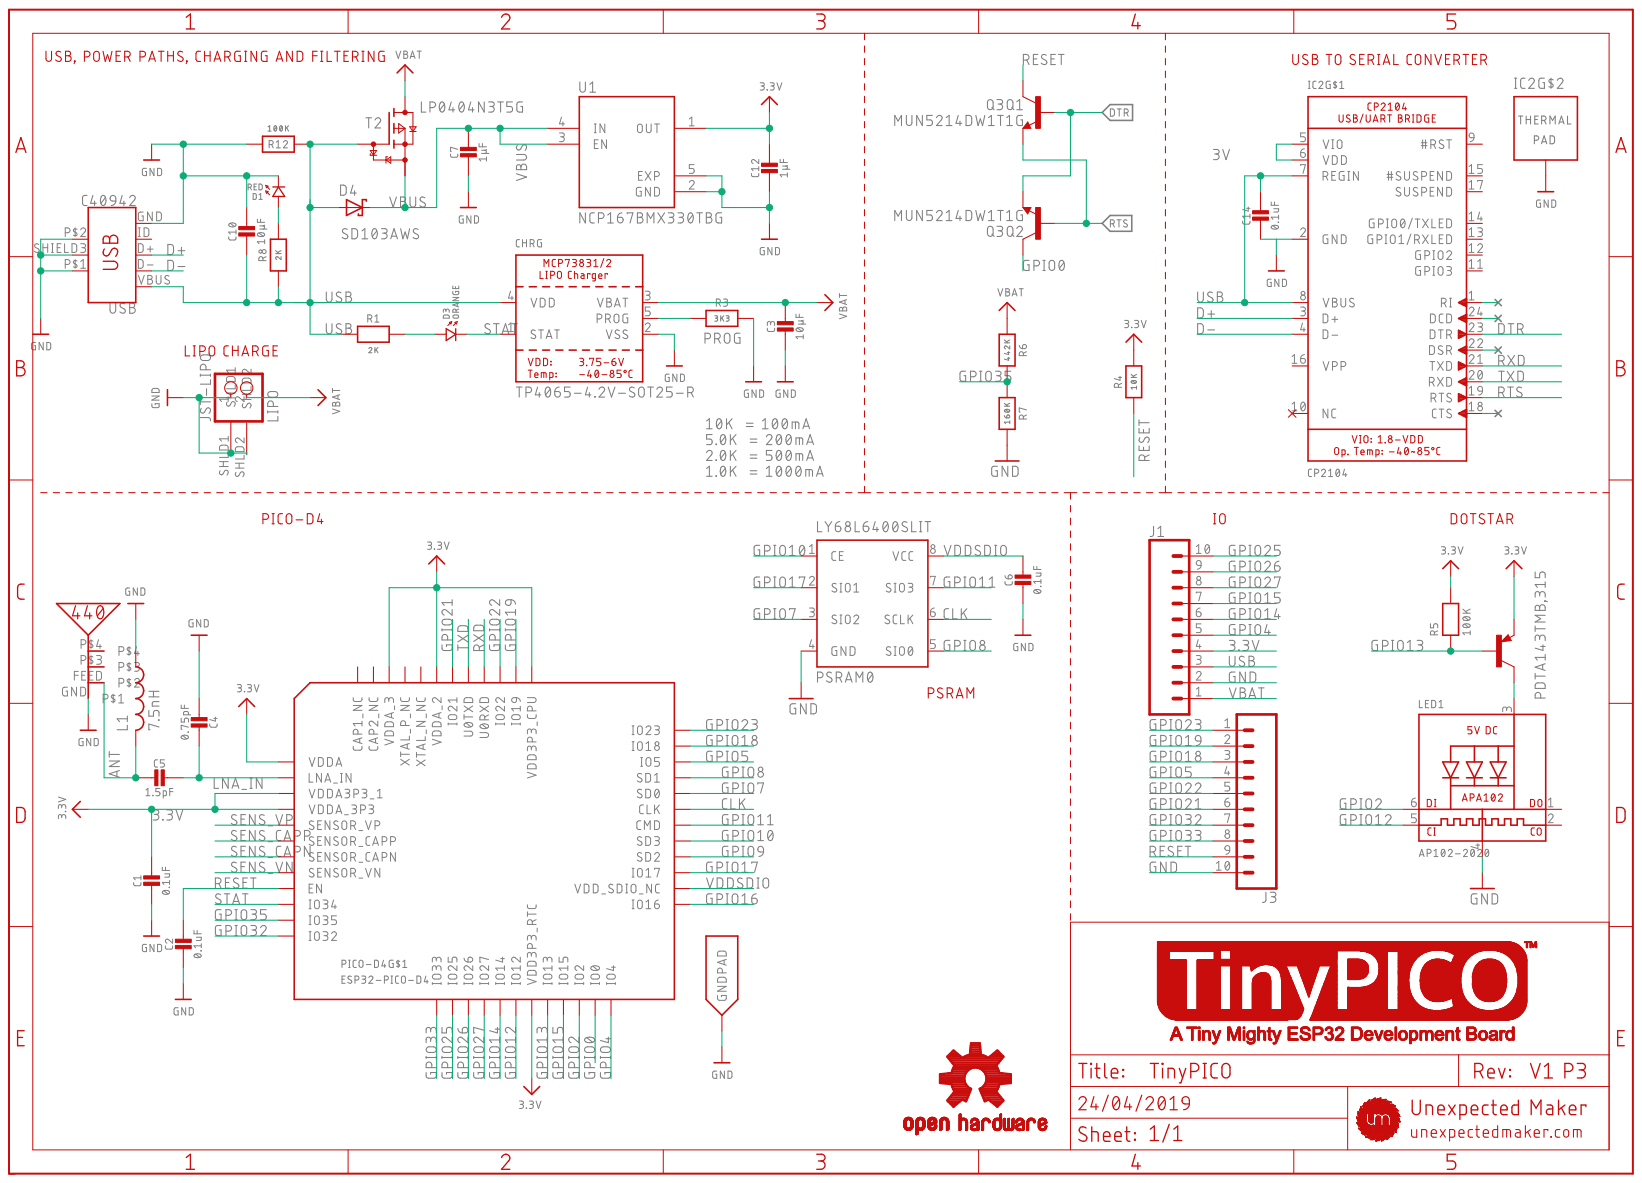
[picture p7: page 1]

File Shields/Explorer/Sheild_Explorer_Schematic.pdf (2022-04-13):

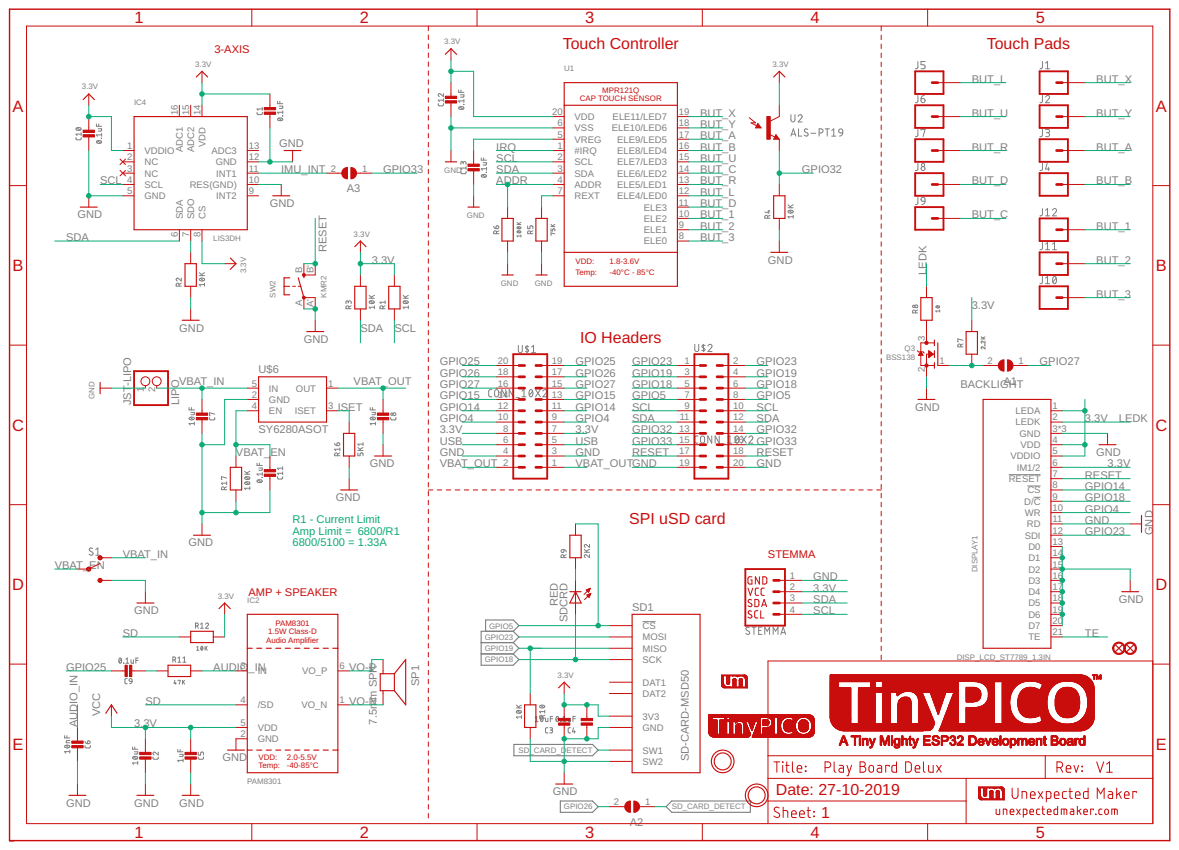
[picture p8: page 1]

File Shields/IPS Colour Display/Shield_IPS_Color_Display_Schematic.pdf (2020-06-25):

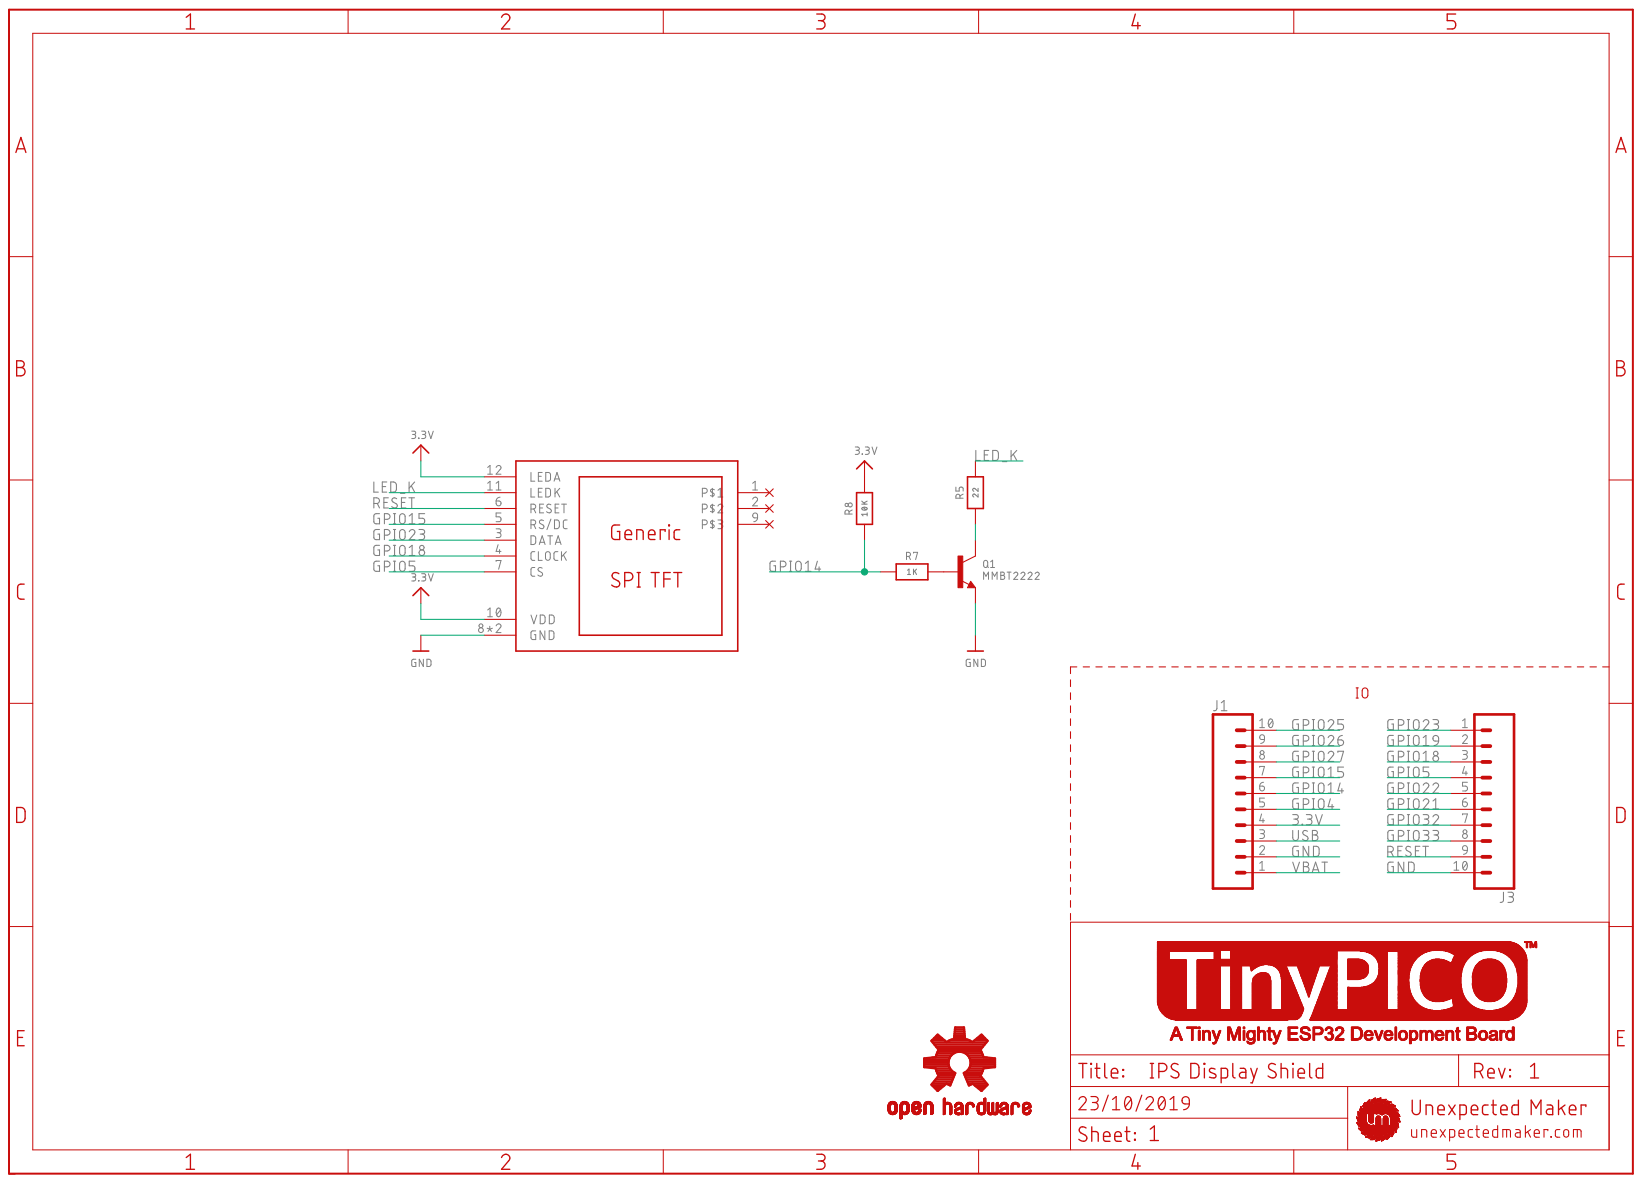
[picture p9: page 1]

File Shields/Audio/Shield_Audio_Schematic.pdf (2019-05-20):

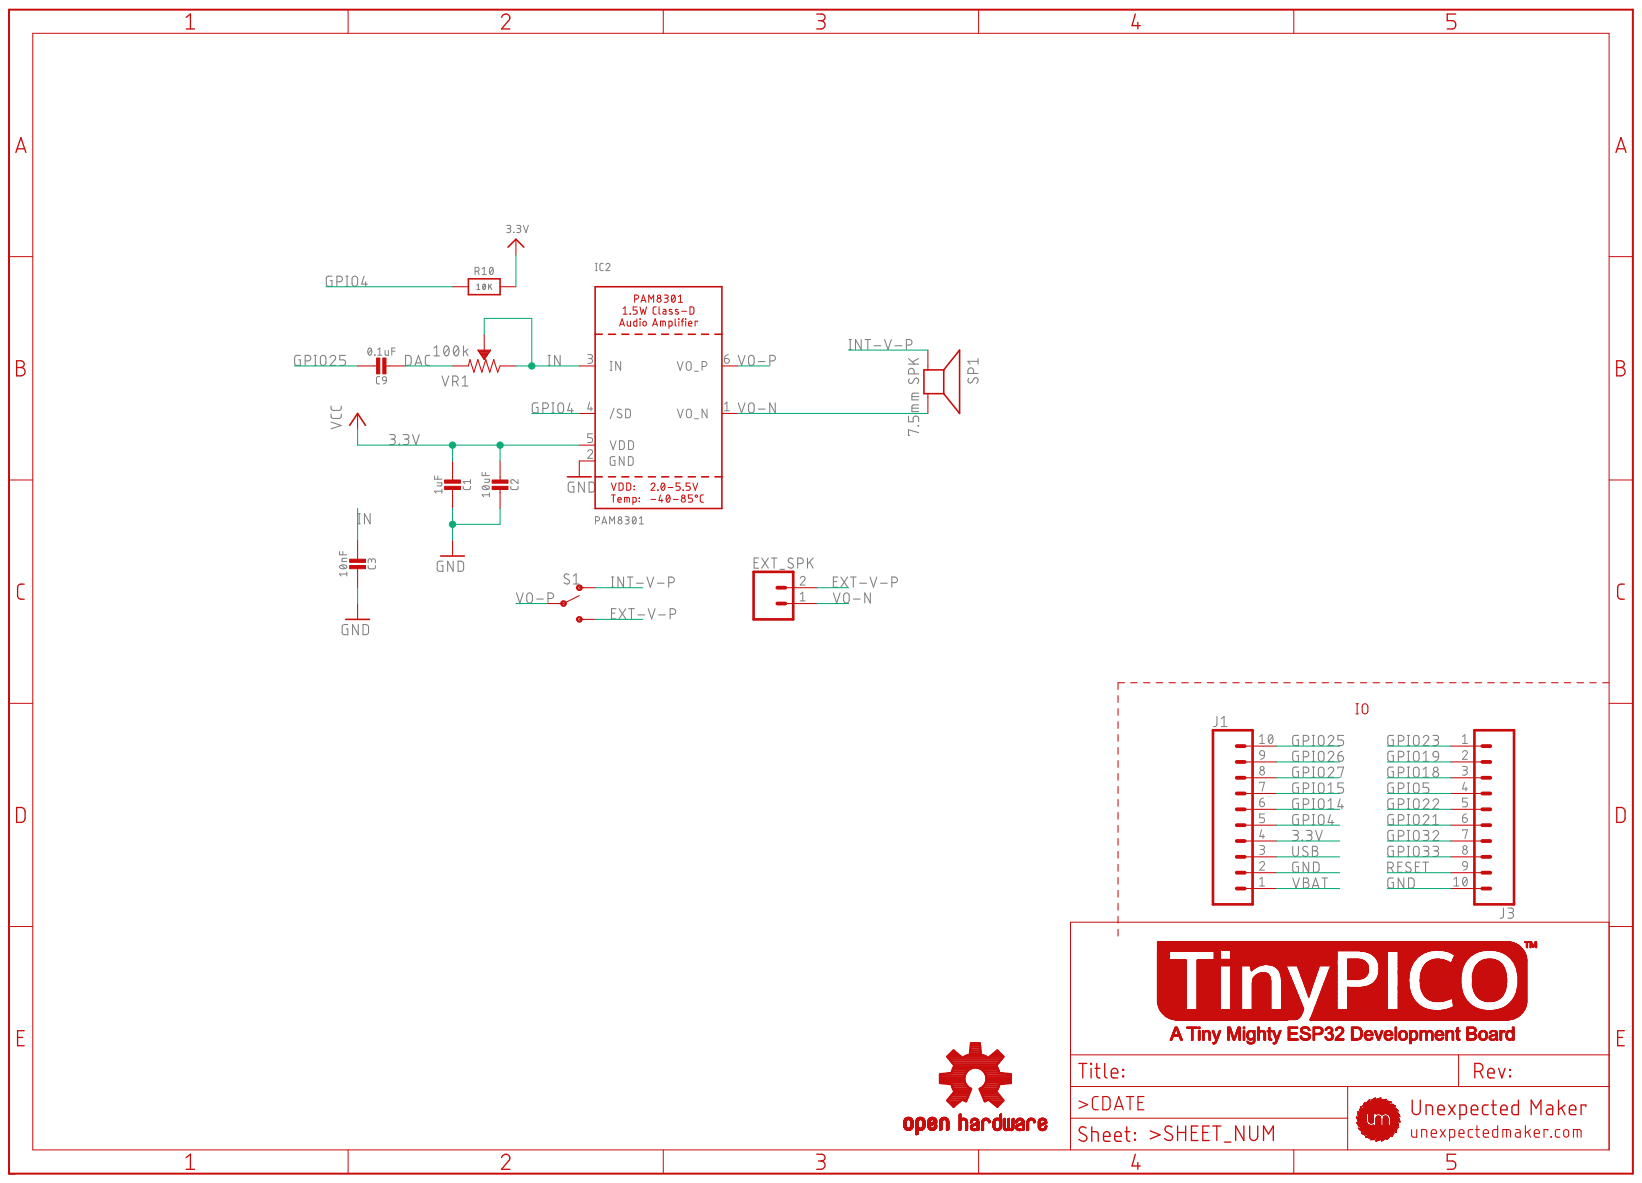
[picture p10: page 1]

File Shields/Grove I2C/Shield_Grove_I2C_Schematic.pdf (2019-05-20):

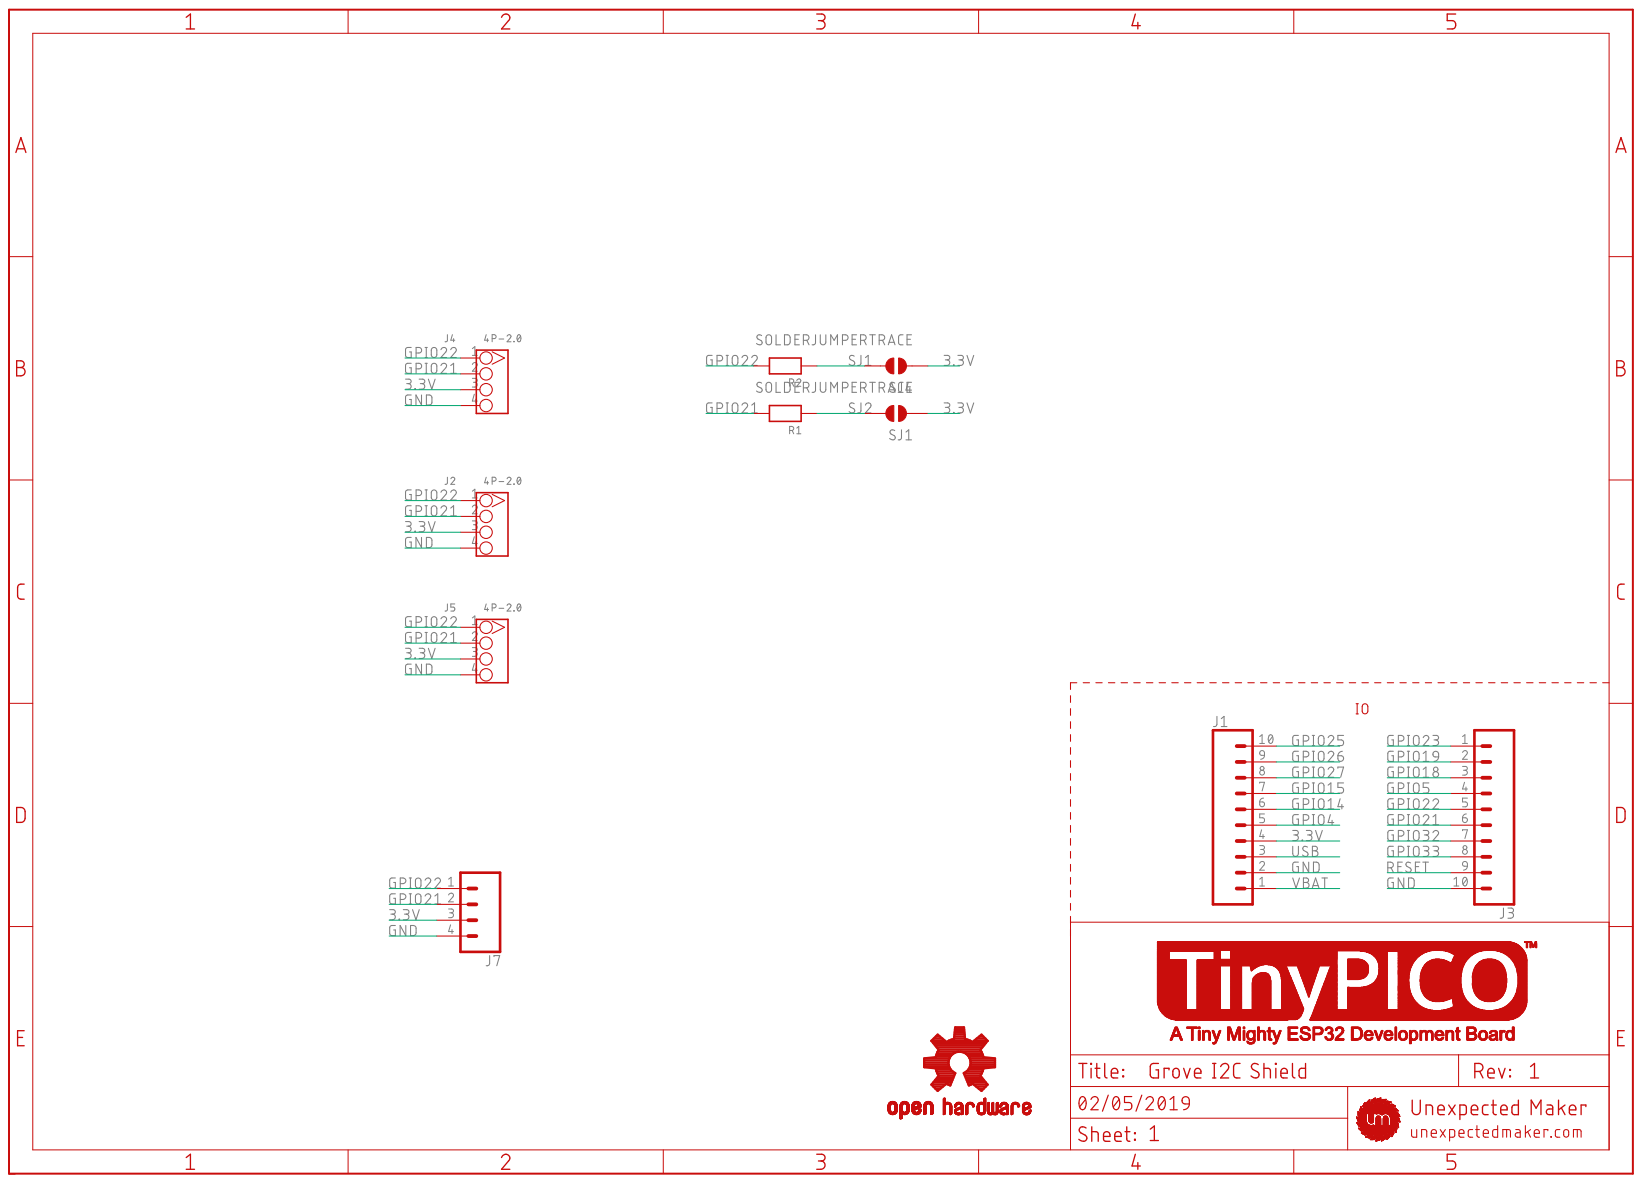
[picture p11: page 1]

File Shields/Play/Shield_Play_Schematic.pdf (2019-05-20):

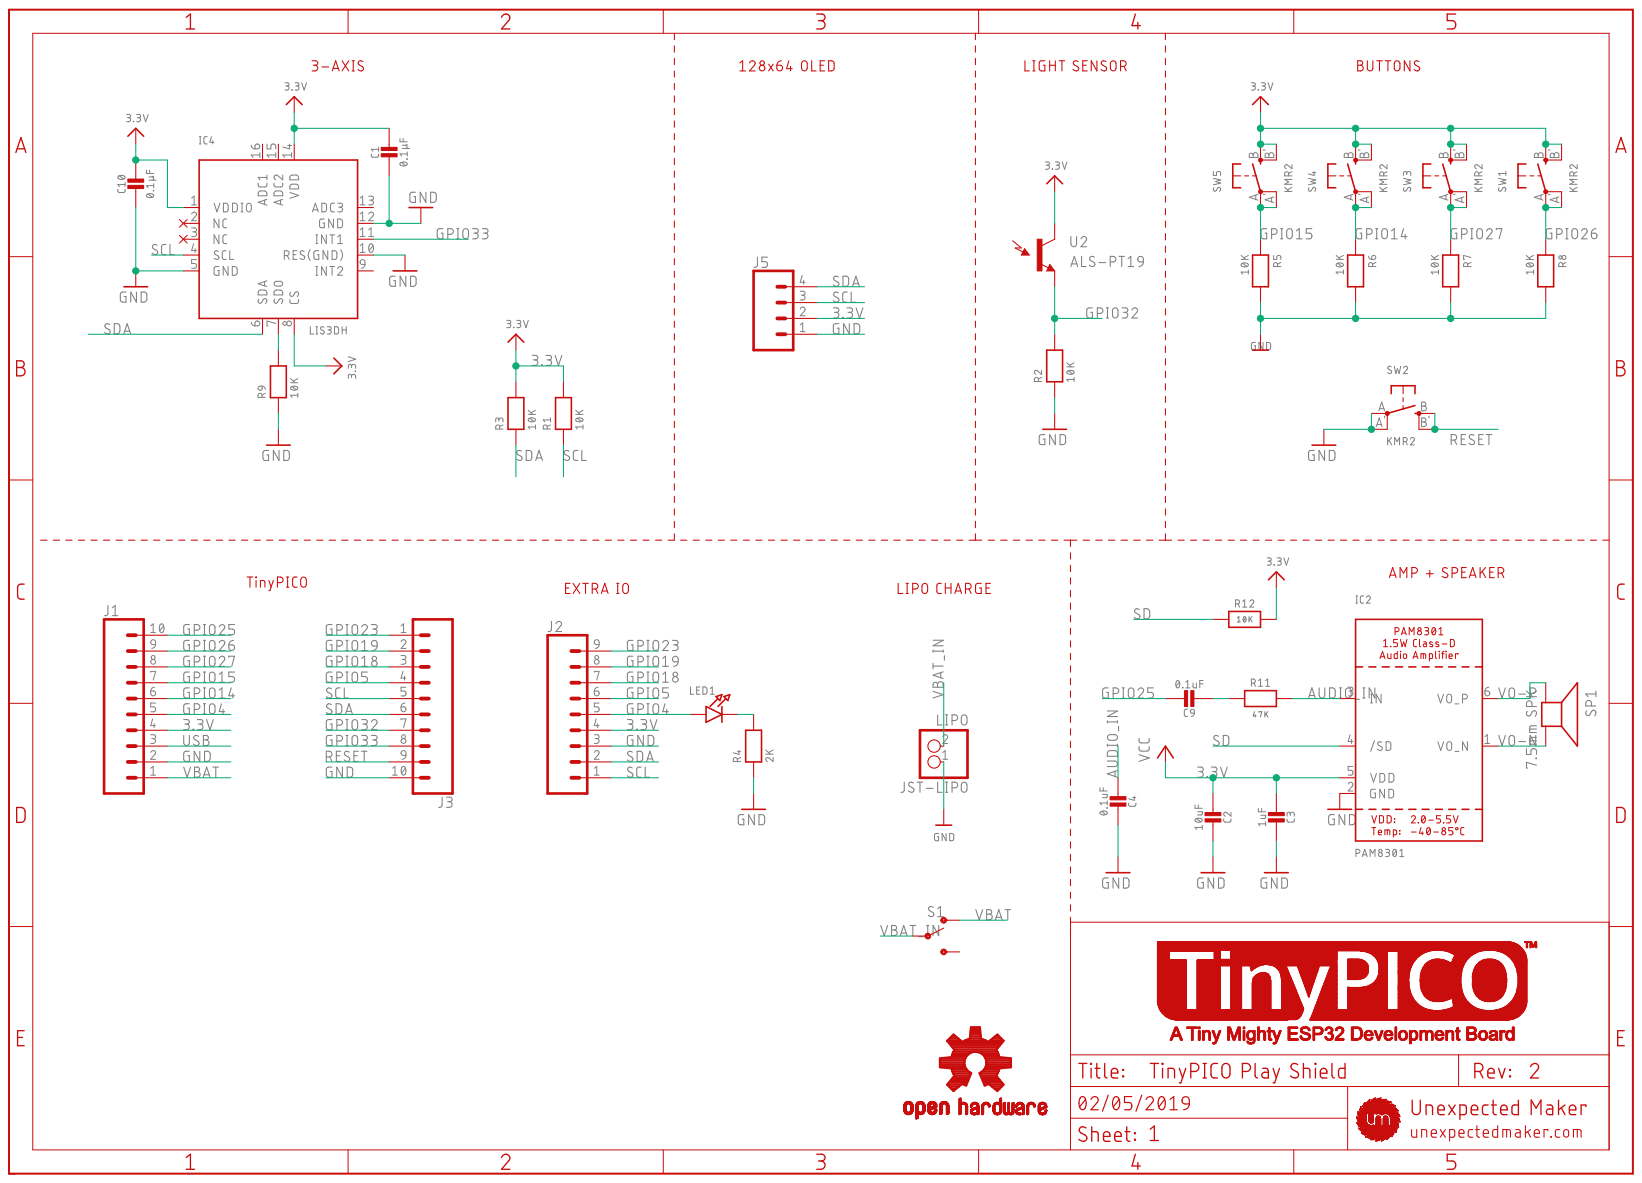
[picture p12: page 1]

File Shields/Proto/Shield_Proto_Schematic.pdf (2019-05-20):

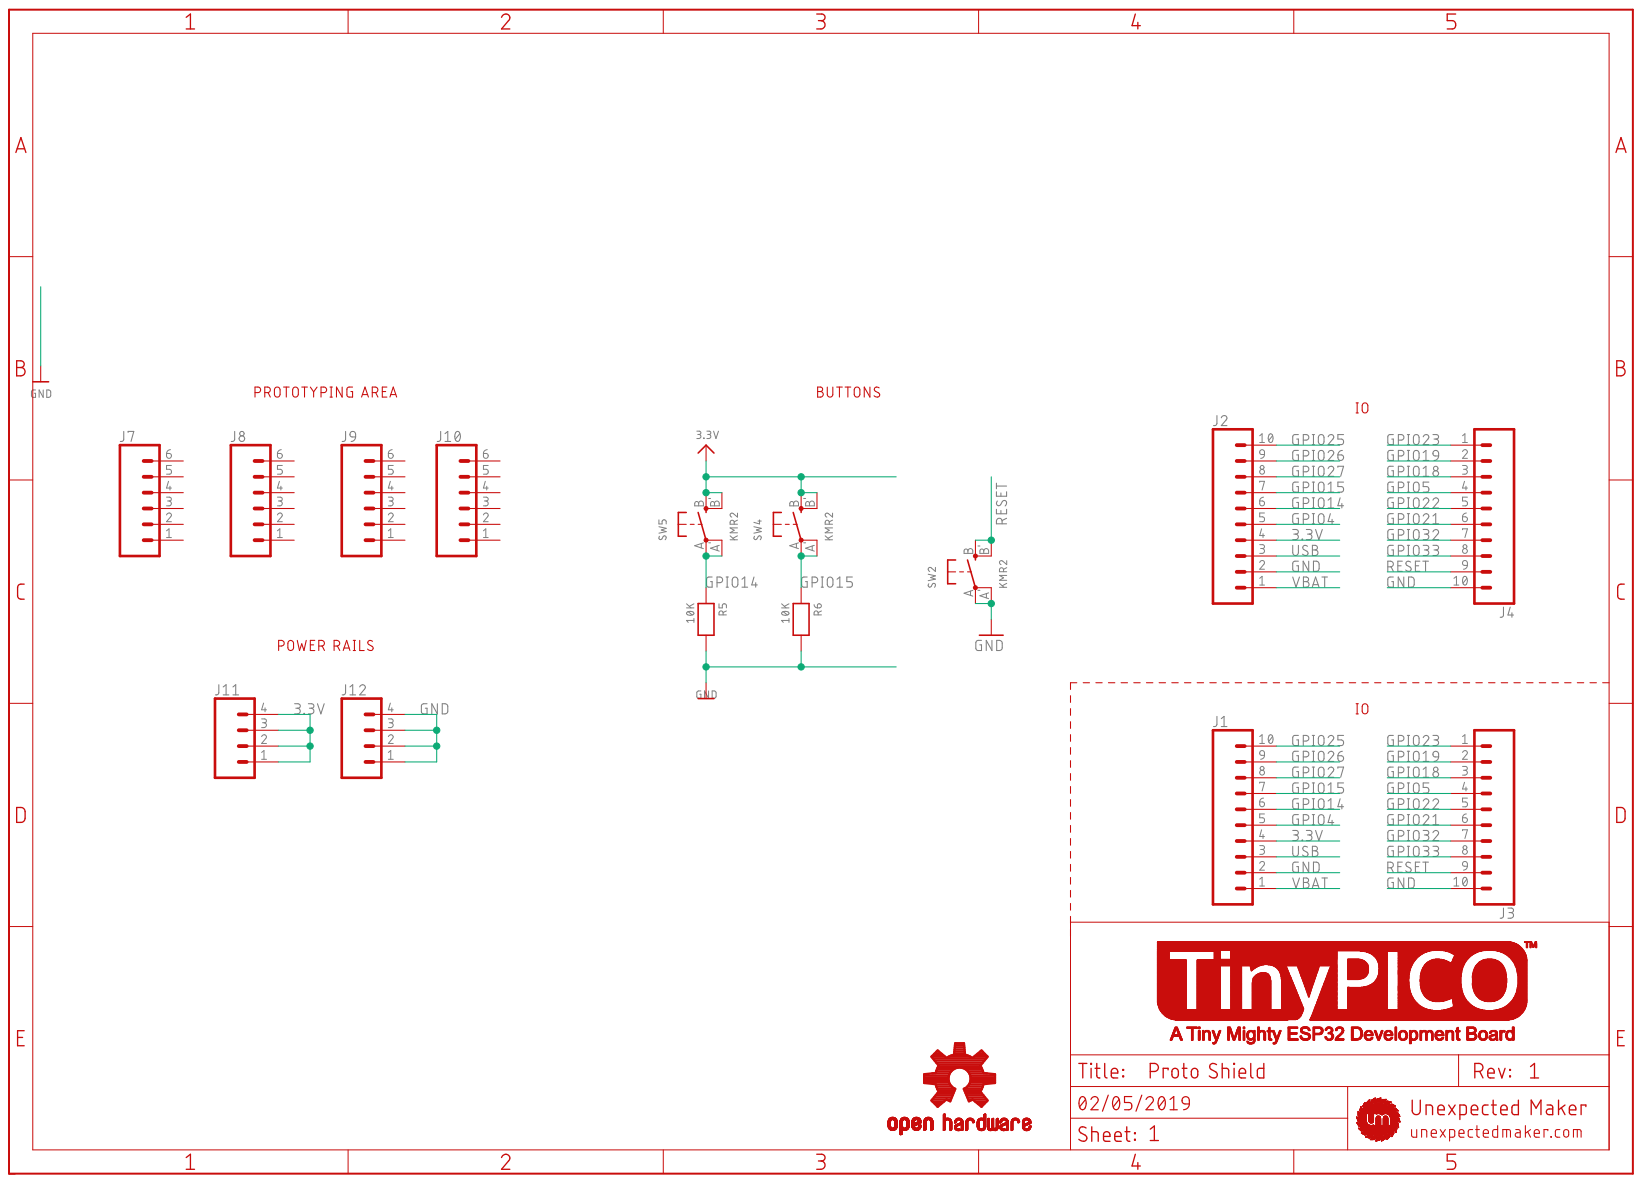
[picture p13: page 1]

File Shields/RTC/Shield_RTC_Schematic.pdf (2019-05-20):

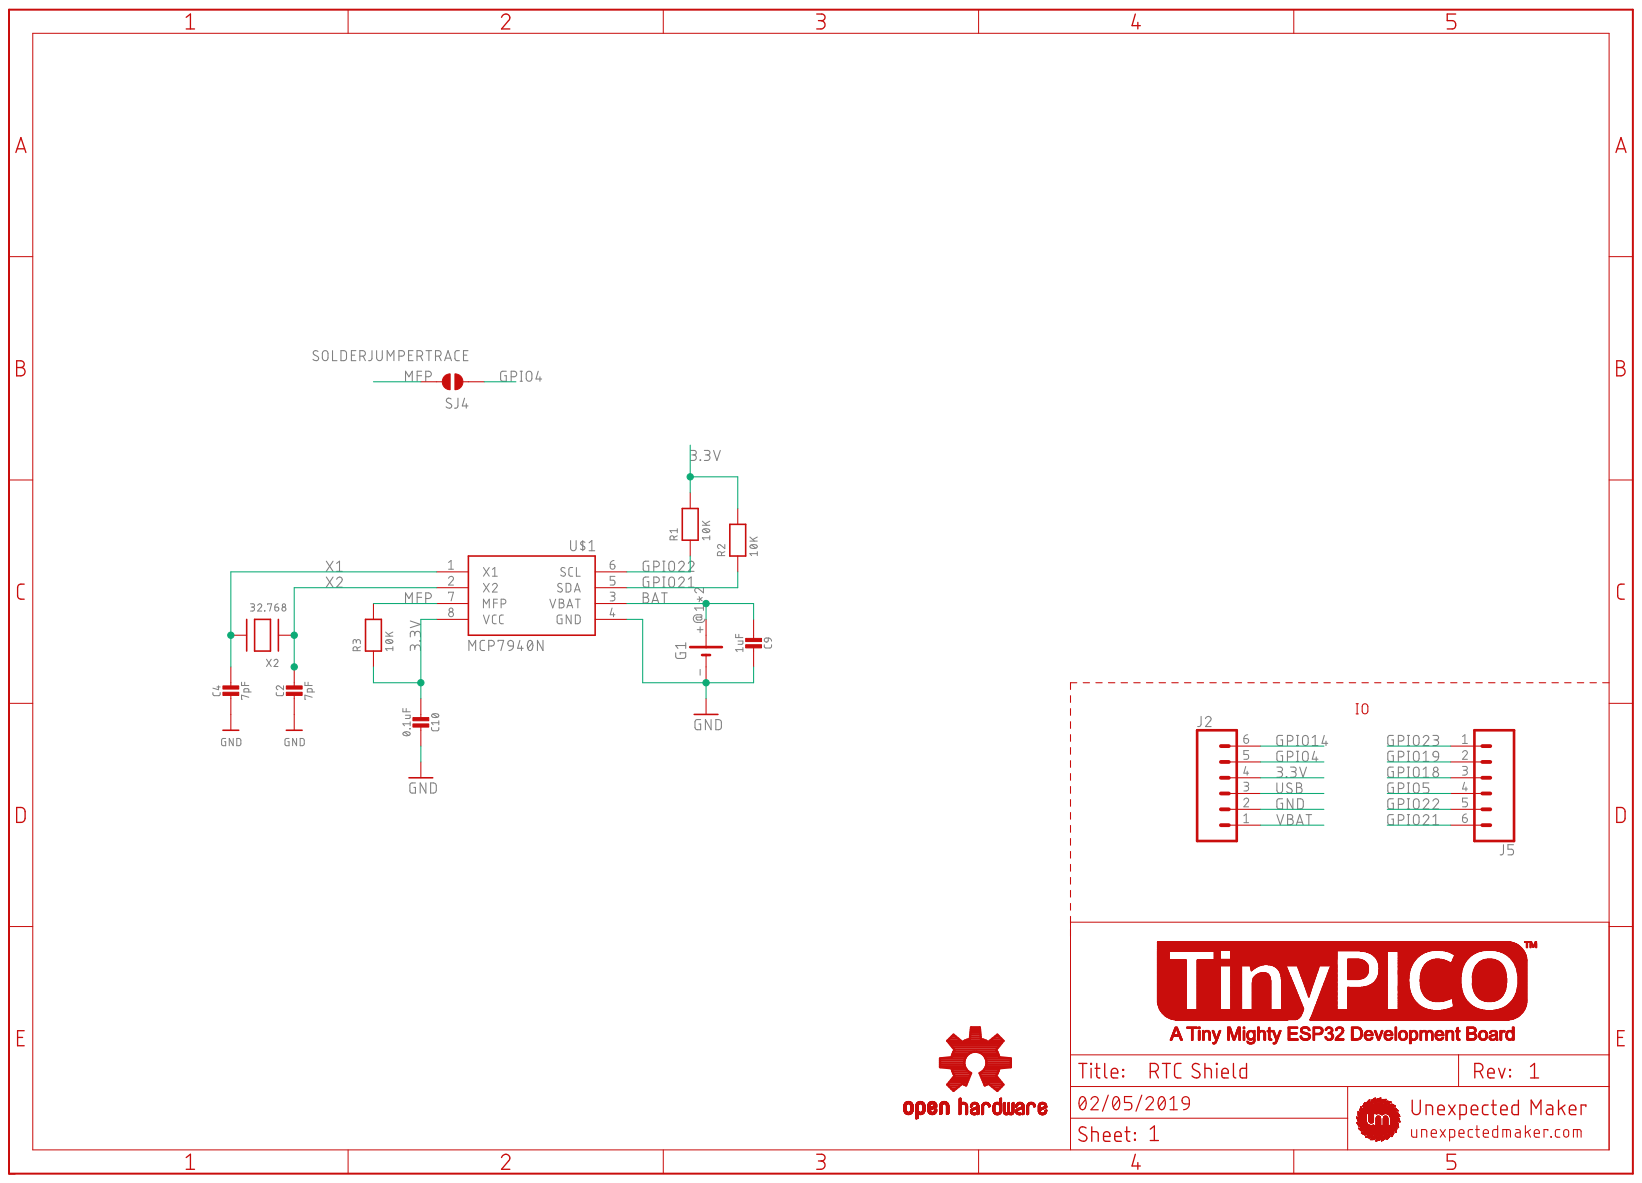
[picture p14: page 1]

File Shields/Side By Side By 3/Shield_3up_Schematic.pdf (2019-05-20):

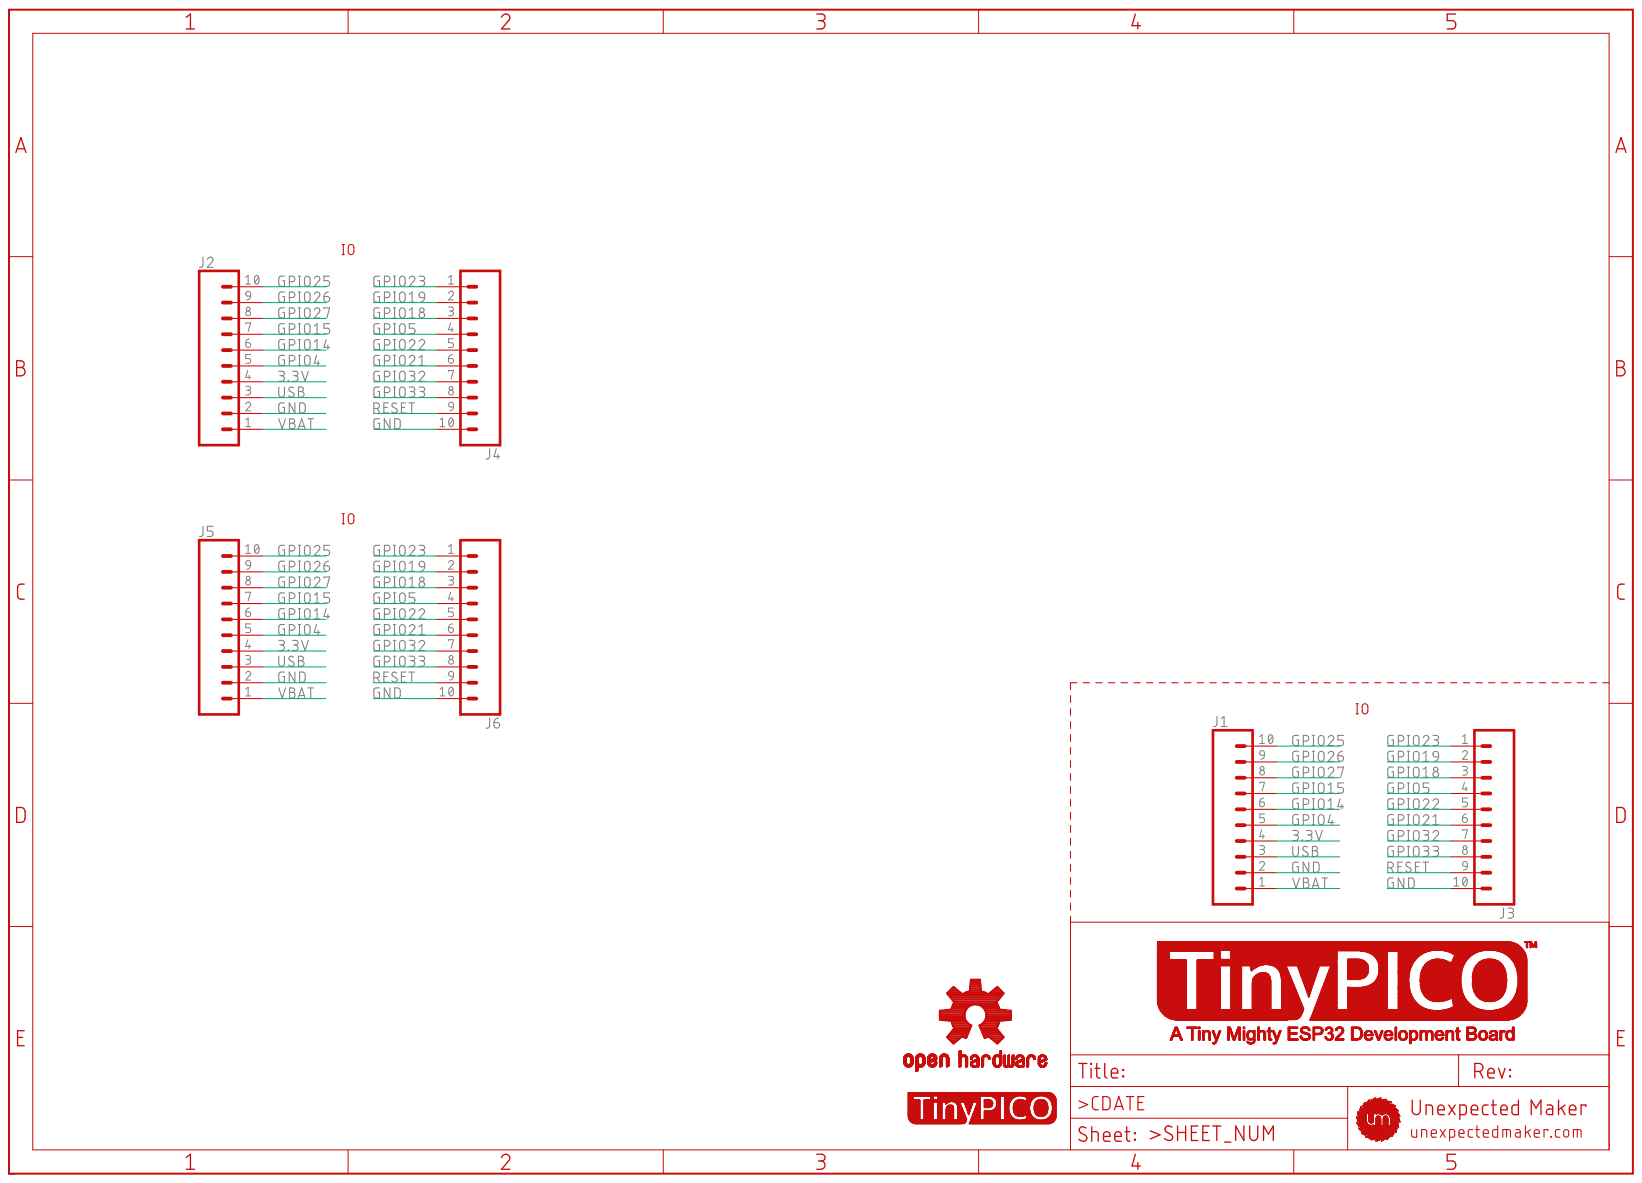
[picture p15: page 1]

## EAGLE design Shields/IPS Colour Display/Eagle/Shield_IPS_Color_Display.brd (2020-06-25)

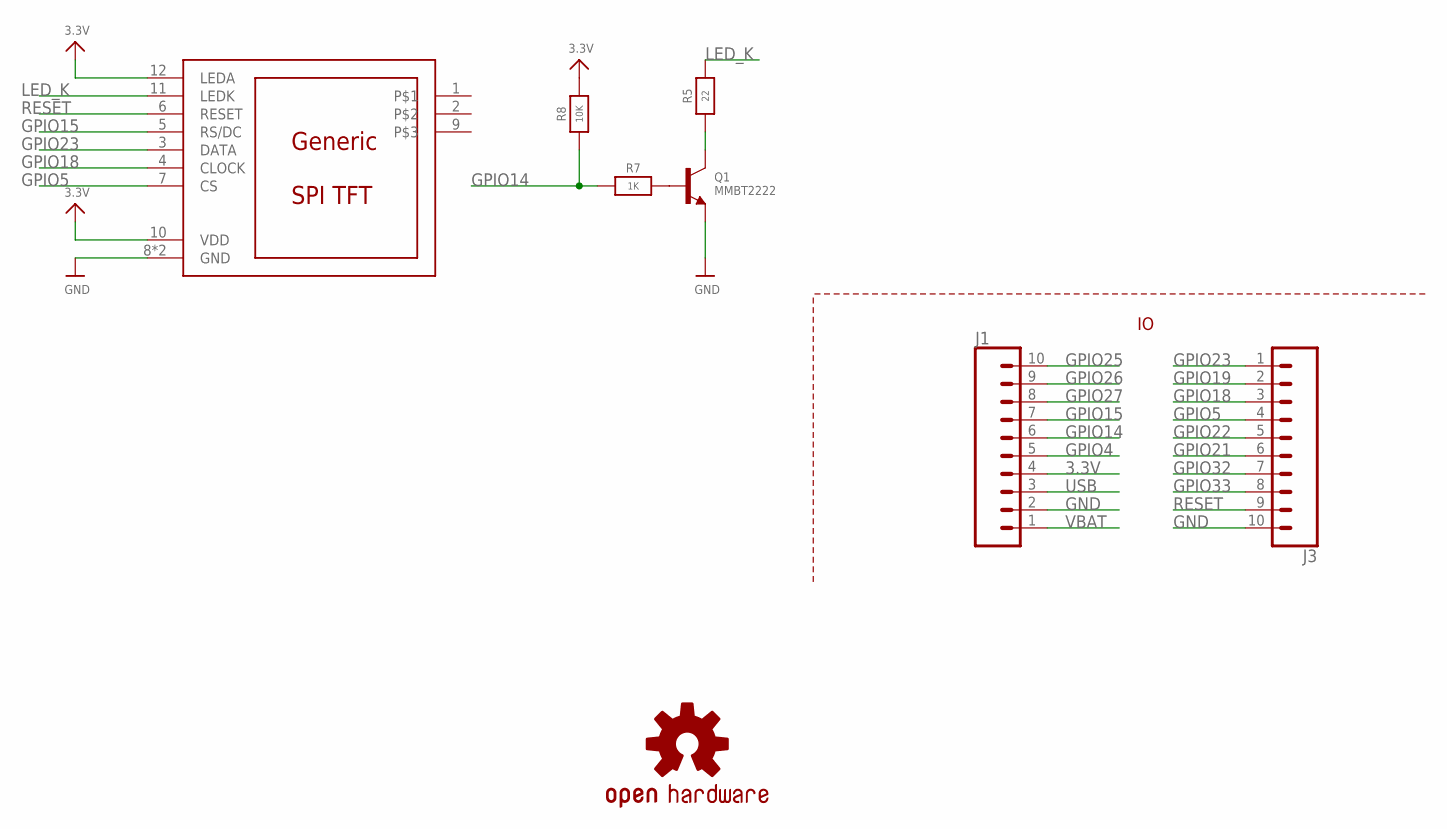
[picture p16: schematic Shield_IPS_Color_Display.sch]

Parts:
J1, J3: TINYPICO_HEADER_10SQR; 1X10_NO_SILK_SQR
LOGO1: OSHW-LOGOS; OSHW-LOGO-S
Q1: MMBT2222; SOT23-WIDE
R5: 22; _0603MP
R7: 1K; _0603MP
R8: 10K; _0603MP
U$2: MICROBUILDER_DISP_LCD_0.9IN_160X80; MICROBUILDER_TFT_0.96IN_160X80

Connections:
3.3V: J1.4, R8.2, U$2.10 (VDD), U$2.12 (LEDA)
GND: J1.2, J3.10, Q1.2 (E), U$2.8 (GND), U$2.13 (GND)
GPIO4: J1.5
GPIO5: J3.4, U$2.7 (CS)
GPIO14: J1.6, R7.1, R8.1
GPIO15: J1.7, U$2.5 (RS/DC)
GPIO18: J3.3, U$2.4 (CLOCK)
GPIO19: J3.2
GPIO21: J3.6
GPIO22: J3.5
GPIO23: J3.1, U$2.3 (DATA)
GPIO25: J1.10
GPIO26: J1.9
GPIO27: J1.8
GPIO32: J3.7
GPIO33: J3.8
LED_K: R5.2, U$2.11 (LEDK)
unnamed: Q1.1 (B), R7.2
unnamed: Q1.3 (C), R5.1
RESET: J3.9, U$2.6 (RESET)
USB: J1.3
VBAT: J1.1

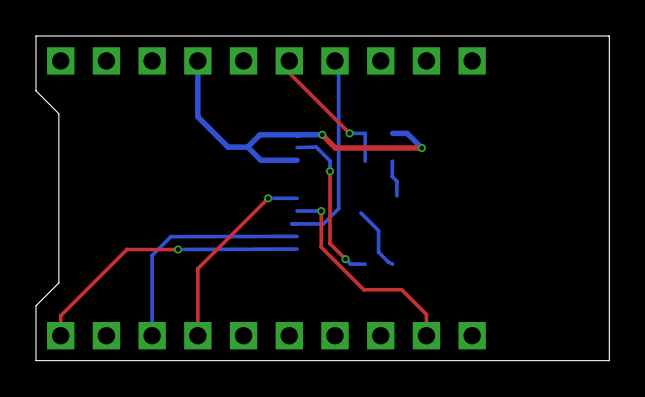
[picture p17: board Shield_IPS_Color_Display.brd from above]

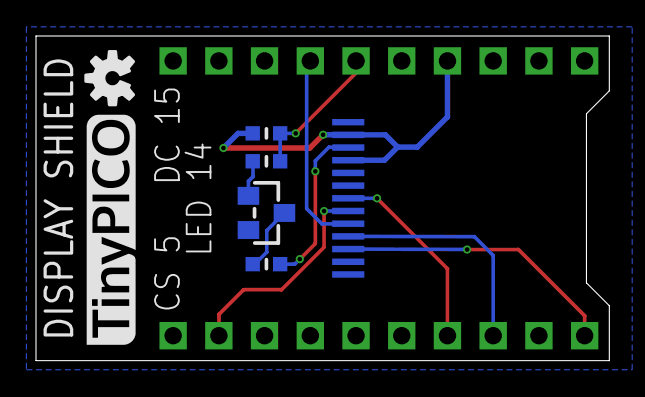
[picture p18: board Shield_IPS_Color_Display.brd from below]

Board: 2 copper layers, 31.9 x 18.0 mm, 8 parts (6 on the bottom side), 11 nets.

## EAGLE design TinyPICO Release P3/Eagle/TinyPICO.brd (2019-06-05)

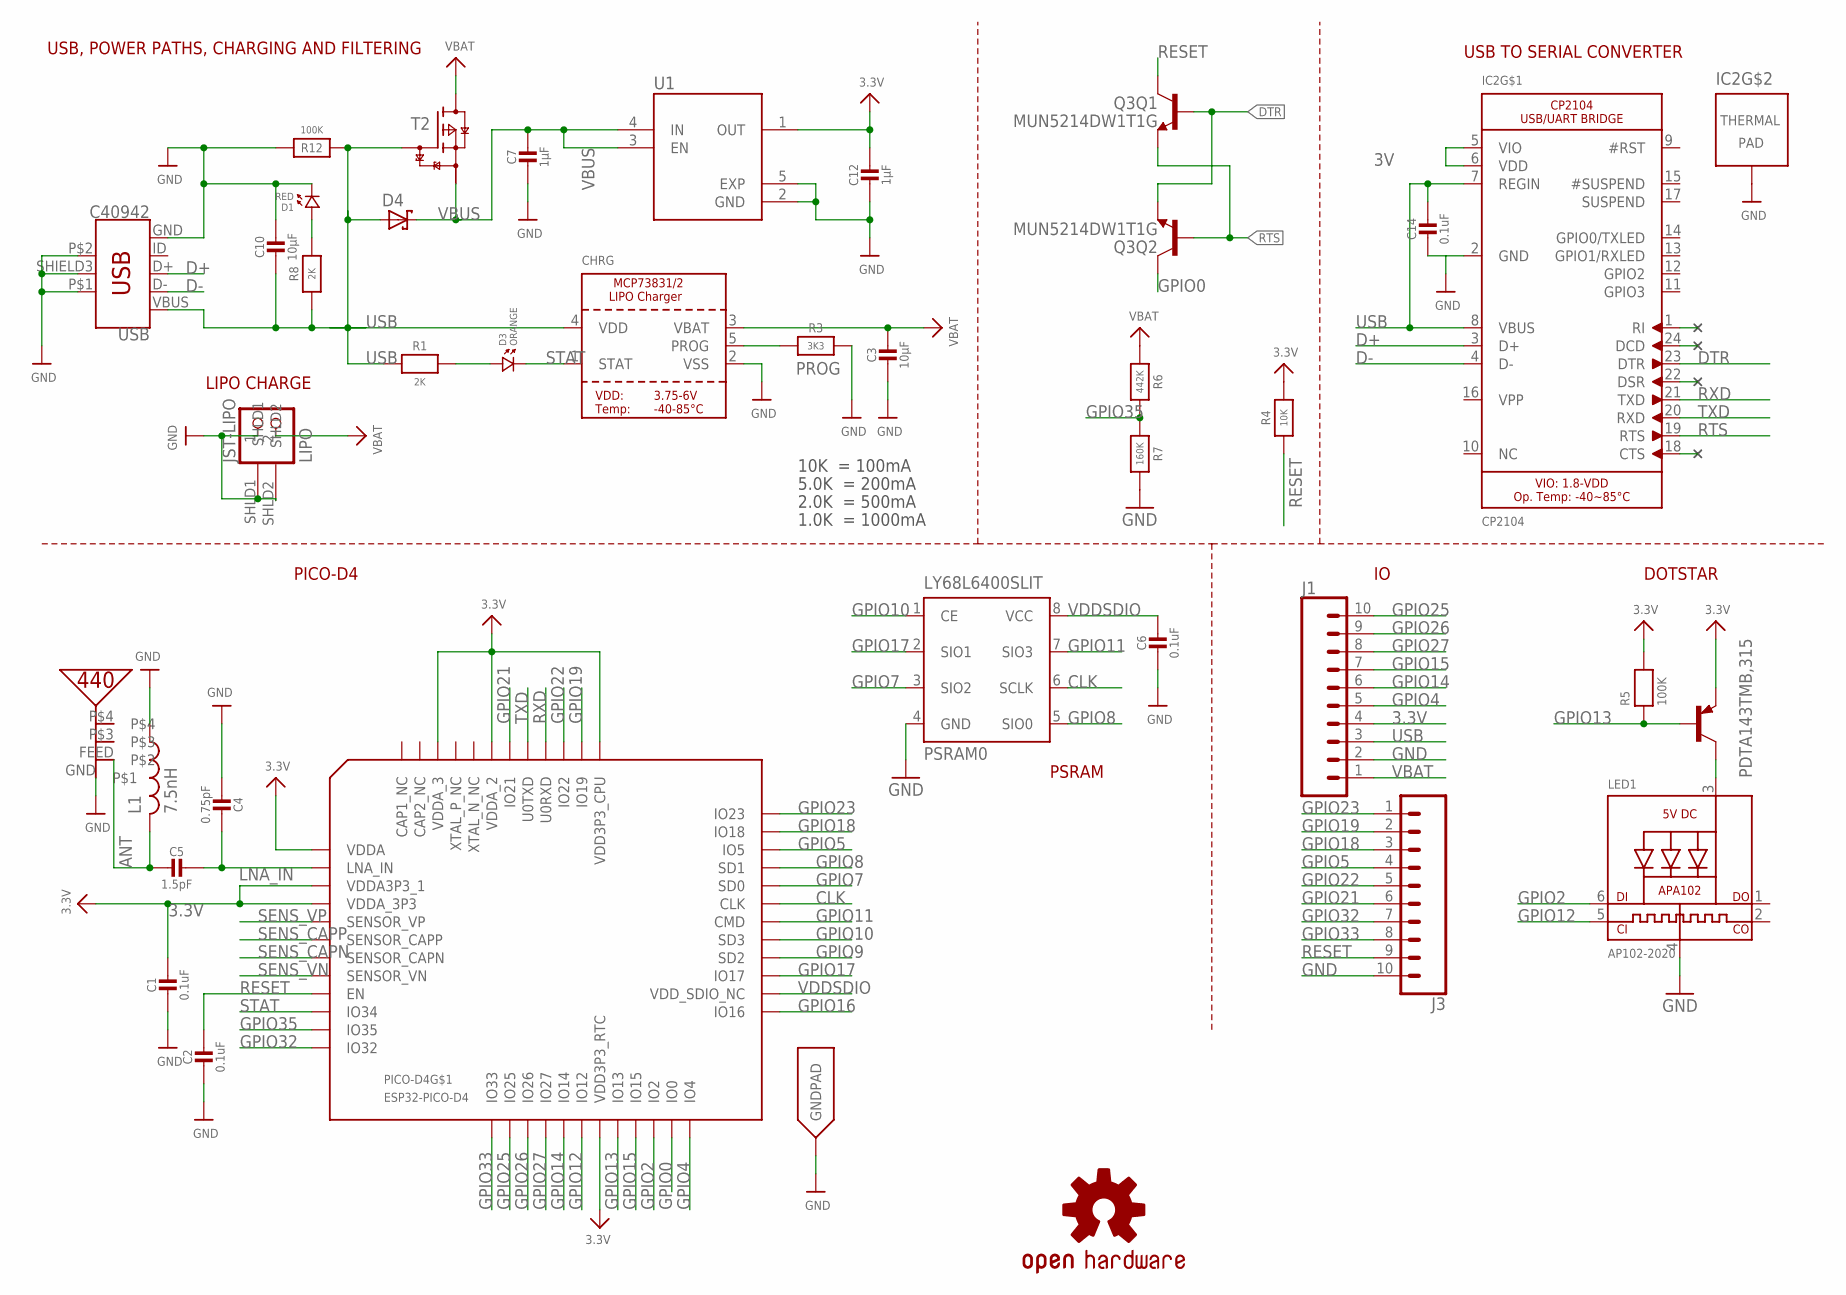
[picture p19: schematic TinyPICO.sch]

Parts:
C1, C2, C6, C14: 0.1uF; _0402MP
C3, C10: 10µF; _0603MP
C4: 0.75pF; _0402MP
C5: 1.5pF; _0402MP
C7, C12: 1µF; _0402MP
CHRG: TP4065-4.2V-SOT25-R; SOT23-5
D1: RED; 0402.LED
D3: ORANGE; 0402.LED
D4: BAT60J; SOD323_ST
IC2: CP2104; MICROBUILDER_QFN24_4MM_SMSC
J1, J3: TINYPICO_HEADER_10NO_SILK_PTH_FEMALE; 1X10_NO_SILK
JST-LIPO: LIPO; JSTPH2
L1: 7.5nH; RESC0402_N
LED1: AP102-2020; MICROBUILDER_APA102_2020
LOGO1: OSHW-LOGOS; OSHW-LOGO-S
LY68L6400SLIT: PSRAM0; SOP8
PDTA143TMB,315: TINYPICO-PNPAMB; SOT883(B)
PICO-D4: ESP32-PICO-D4; PICO-D4-QFN48
Q3: MUN5214DW1T1G; DUAL_NPN_SC70-6
R1, R8: 2K; _0402MP
R3: 3K3; _0402MP
R4: 10K; _0402MP
R5, R12: 100K; _0402MP
R6: 442K; _0402MP
R7: 160K; _0402MP
T2: TINYPICO-P-FETKMB; SOT883(B)
U1: NCP170AMX300TCG; VREG_NCP170AMX300TCG
U$8: PRO-OB-440
USB: C40942; USB-B-MICRO-SMD

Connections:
3.3V: C1.1, C12.1, J1.4, PDTA143TMB,315.2 (E), PICO-D4.1 (VDDA), PICO-D4.3 (VDDA3P3_1), PICO-D4.4 (VDDA_3P3), PICO-D4.19 (VDD3P3_RTC), PICO-D4.37 (VDD3P3_CPU), PICO-D4.43 (VDDA_2), PICO-D4.46 (VDDA_3), R4.2, R5.2, U1.1 (OUT)
3V: IC2.5 (VIO), IC2.6 (VDD)
ANT: C5.2, L1.2, U$8.FEED
CLK: LY68L6400SLIT.6 (SCLK), PICO-D4.31 (CLK)
D+: IC2.3 (D+), USB.D+
D-: IC2.4 (D-), USB.D-
DTR: IC2.23 (DTR), Q3.1 (E), Q3.5 (B)
GND: C1.2, C2.2, C3.2, C4.2, C6.2, C7.2, C10.1, C12.2, C14.2, CHRG.2 (VSS), D1.P$2 (2), IC2.2 (GND), IC2.THERM (TP), J1.2, J3.10, JST-LIPO.1, JST-LIPO.SHLD1, JST-LIPO.SHLD2, L1.1, LED1.4 (GND), LY68L6400SLIT.4 (GND), PICO-D4.EXP (GNDPAD), R3.2, R7.2, R12.2, U1.2 (GND), U1.5 (EXP), U$8.GND, USB.GND, USB.P$1 (SHIELD1), USB.P$2 (SHIELD2), USB.SHIELD3 (SHIELD)
GPIO0: PICO-D4.23 (IO0), Q3.6 (C)
GPIO2: LED1.6 (DI), PICO-D4.22 (IO2)
GPIO4: J1.5, PICO-D4.24 (IO4)
GPIO5: J3.4, PICO-D4.34 (IO5)
GPIO7: LY68L6400SLIT.3 (SIO2), PICO-D4.32 (SD0)
GPIO8: LY68L6400SLIT.5 (SIO0), PICO-D4.33 (SD1)
GPIO9: PICO-D4.28 (SD2)
GPIO10: LY68L6400SLIT.1 (CE), PICO-D4.29 (SD3)
GPIO11: LY68L6400SLIT.7 (SIO3), PICO-D4.30 (CMD)
GPIO12: LED1.5 (CKI), PICO-D4.18 (IO12)
GPIO13: PDTA143TMB,315.1 (B), PICO-D4.20 (IO13), R5.1
GPIO14: J1.6, PICO-D4.17 (IO14)
GPIO15: J1.7, PICO-D4.21 (IO15)
GPIO16: PICO-D4.25 (IO16)
GPIO17: LY68L6400SLIT.2 (SIO1), PICO-D4.27 (IO17)
GPIO18: J3.3, PICO-D4.35 (IO18)
GPIO19: J3.2, PICO-D4.38 (IO19)
GPIO21: J3.6, PICO-D4.42 (IO21)
GPIO22: J3.5, PICO-D4.39 (IO22)
GPIO23: J3.1, PICO-D4.36 (IO23)
GPIO25: J1.10, PICO-D4.14 (IO25)
GPIO26: J1.9, PICO-D4.15 (IO26)
GPIO27: J1.8, PICO-D4.16 (IO27)
GPIO32: J3.7, PICO-D4.12 (IO32)
GPIO33: J3.8, PICO-D4.13 (IO33)
GPIO35: PICO-D4.11 (IO35), R6.2, R7.1
LNA_IN: C4.1, C5.1, PICO-D4.2 (LNA_IN)
unnamed: D1.P$1 (1), R8.2
unnamed: D3.P$1 (1), R1.2
unnamed: LED1.3 (VDD), PDTA143TMB,315.3 (C)
PROG: CHRG.5 (PROG), R3.1
RESET: C2.1, J3.9, PICO-D4.9 (EN), Q3.3 (C), R4.1
RTS: IC2.19 (RTS), Q3.2 (B), Q3.4 (E)
RXD: IC2.21 (TXD), PICO-D4.40 (U0RXD)
SENS_CAPN: PICO-D4.7 (SENSOR_CAPN)
SENS_CAPP: PICO-D4.6 (SENSOR_CAPP)
SENS_VN: PICO-D4.8 (SENSOR_VN)
SENS_VP: PICO-D4.5 (SENSOR_VP)
STAT: CHRG.1 (STAT), D3.P$2 (2), PICO-D4.10 (IO34)
TXD: IC2.20 (RXD), PICO-D4.41 (U0TXD)
USB: C10.2, C14.1, CHRG.4 (VDD), D4.A, IC2.7 (REGIN), IC2.8 (VBUS), J1.3, R1.1, R8.1, R12.1, T2.1 (G), USB.VBUS
VBAT: C3.1, CHRG.3 (VBAT), J1.1, JST-LIPO.2, R6.1, T2.3 (D)
VBUS: C7.1, D4.C, T2.2 (S), U1.3 (EN), U1.4 (IN)
VDDSDIO: C6.1, LY68L6400SLIT.8 (VCC), PICO-D4.26 (VDD_SDIO_NC)

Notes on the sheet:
USB, POWER PATHS, CHARGING AND FILTERING
LIPO CHARGE
USB TO SERIAL CONVERTER
PICO-D4
10K = 100mA
5.0K = 200mA
2.0K = 500mA
1.0K = 1000mA
PSRAM
DOTSTAR

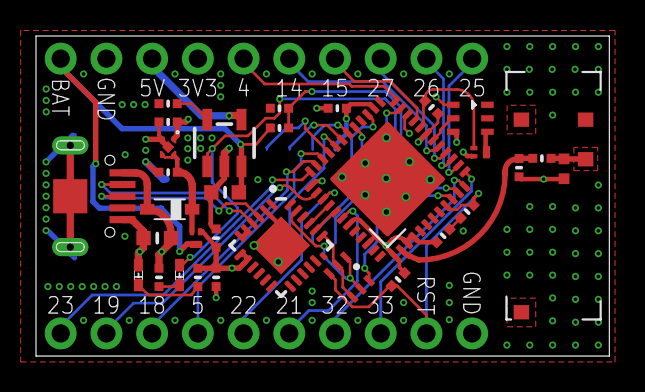
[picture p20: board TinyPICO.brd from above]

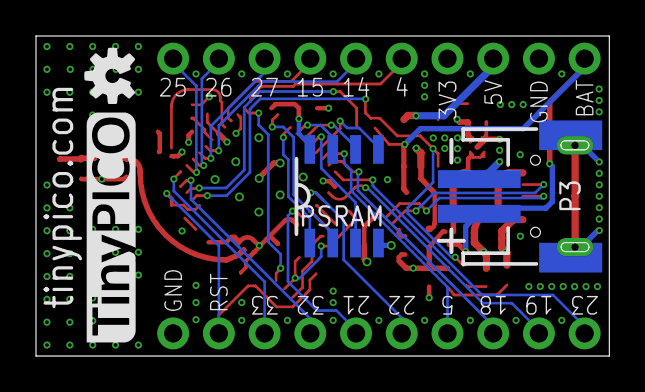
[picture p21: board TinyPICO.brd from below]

Board: 4 copper layers, 31.9 x 17.8 mm, 37 parts (3 on the bottom side), 46 nets.

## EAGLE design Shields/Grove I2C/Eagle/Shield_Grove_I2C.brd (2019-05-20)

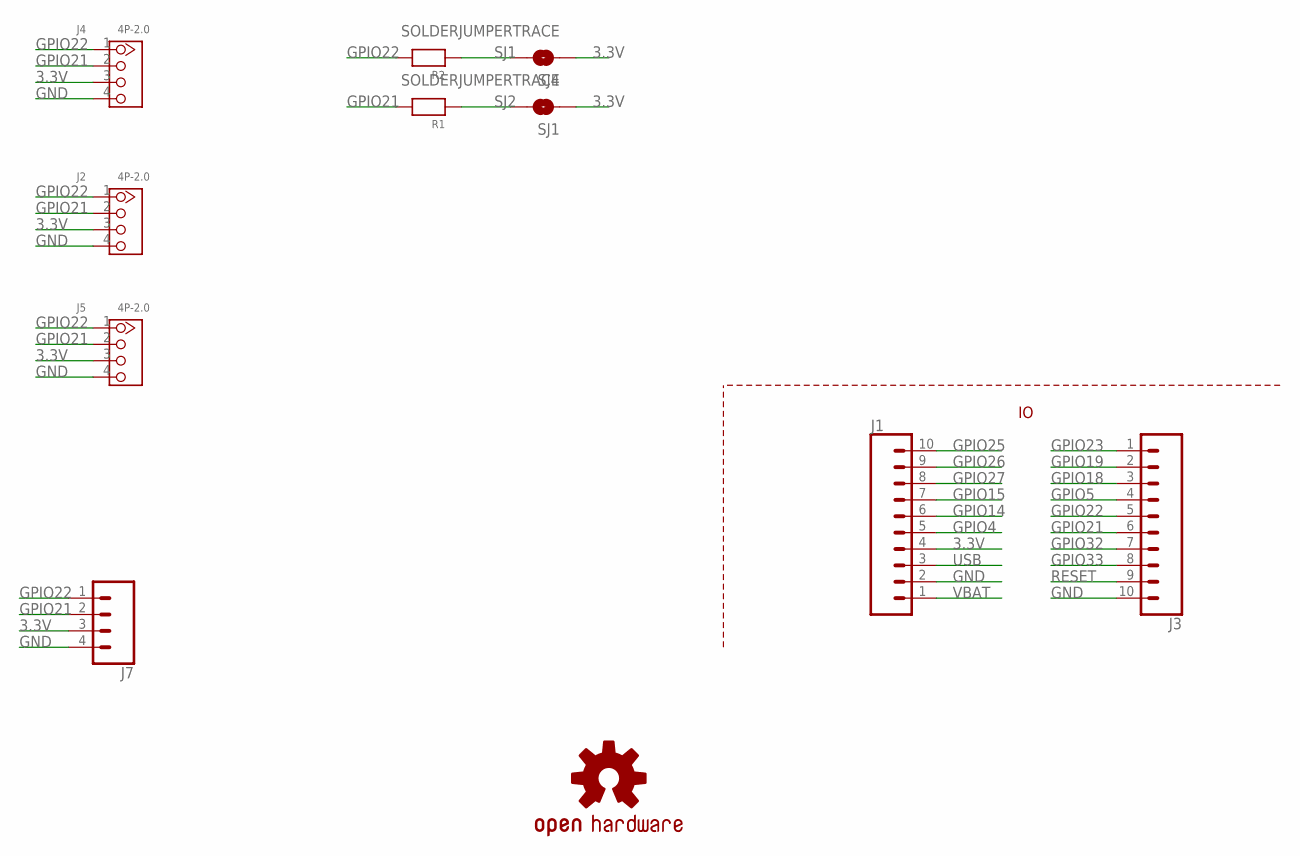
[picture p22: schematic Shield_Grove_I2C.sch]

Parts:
J1, J3: TINYPICO_HEADER_10NO_SILK_PTH_FEMALE; 1X10_NO_SILK
J2, J4, J5: 4P-2.0; HW4-2.0
J7: CONN_041X04_NO_SILK; 1X04_NO_SILK
LOGO1: OSHW-LOGOS; OSHW-LOGO-S
R1, R2: RESISTOR_0603MP; _0603MP
SJ1, SJ4: SOLDERJUMPERTRACE; SPARKFUN_SJ_2S-TRACE

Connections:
3.3V: J1.4, J2.3, J4.3, J5.3, J7.3, SJ1.1, SJ4.1
GND: J1.2, J2.4, J3.10, J4.4, J5.4, J7.4
GPIO4: J1.5
GPIO5: J3.4
GPIO14: J1.6
GPIO15: J1.7
GPIO18: J3.3
GPIO19: J3.2
GPIO21: J2.2, J3.6, J4.2, J5.2, J7.2, R1.2
GPIO22: J2.1, J3.5, J4.1, J5.1, J7.1, R2.2
GPIO23: J3.1
GPIO25: J1.10
GPIO26: J1.9
GPIO27: J1.8
GPIO32: J3.7
GPIO33: J3.8
RESET: J3.9
SJ1: R2.1, SJ4.2
SJ2: R1.1, SJ1.2
USB: J1.3
VBAT: J1.1

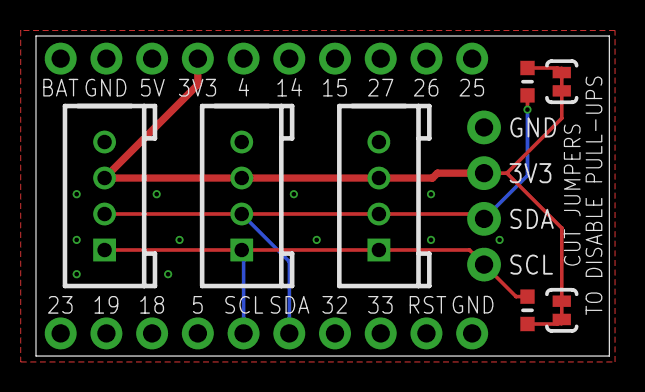
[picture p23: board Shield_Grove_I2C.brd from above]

Board: 2 copper layers, 31.9 x 17.8 mm, 11 parts (1 on the bottom side), 6 nets.

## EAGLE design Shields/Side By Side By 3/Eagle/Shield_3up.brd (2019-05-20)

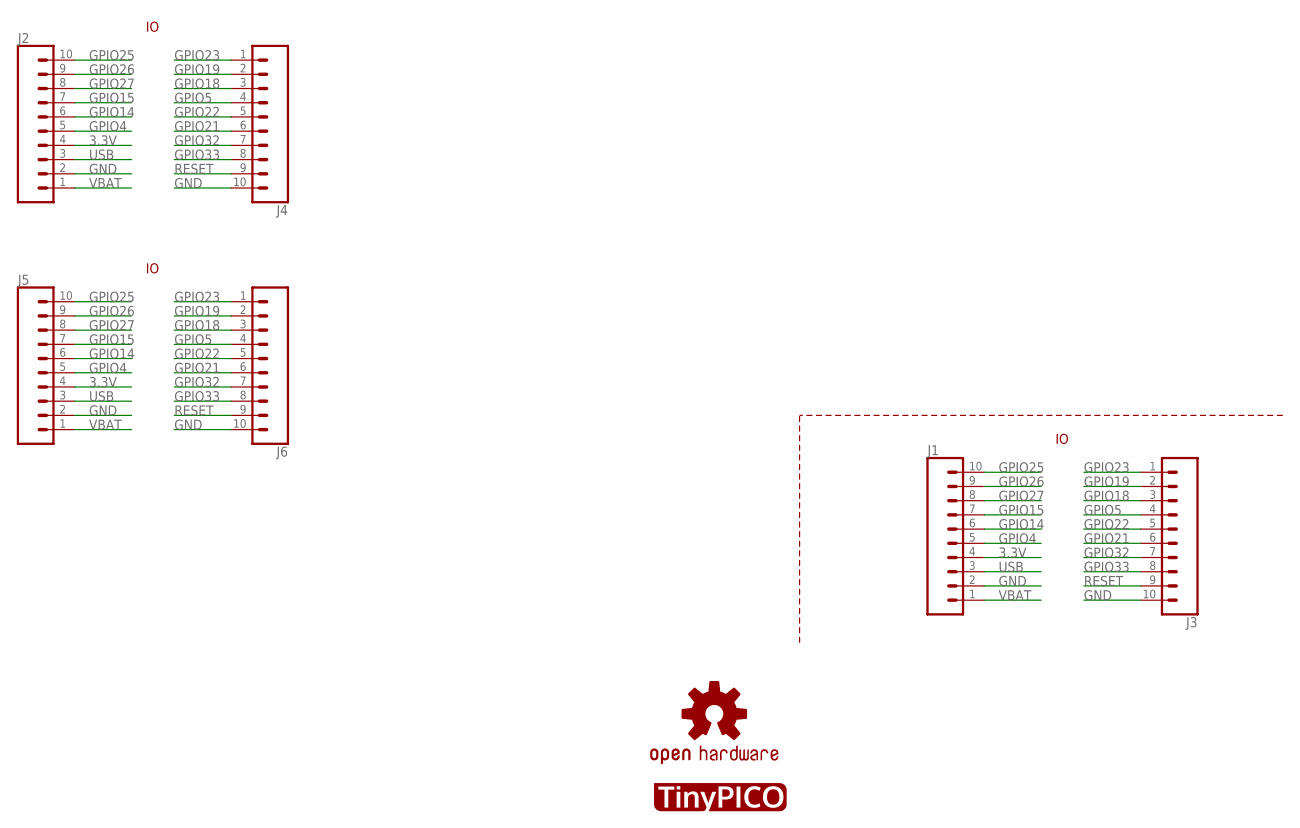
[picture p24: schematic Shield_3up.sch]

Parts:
J1, J2, J3, J4, J5, J6: TINYPICO_HEADER_10NO_SILK_PTH_FEMALE; 1X10_NO_SILK
LOGO1: OSHW-LOGOS; OSHW-LOGO-S
U$1: TP_LOGO

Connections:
3.3V: J1.4, J2.4, J5.4
GND: J1.2, J2.2, J3.10, J4.10, J5.2, J6.10
GPIO4: J1.5, J2.5, J5.5
GPIO5: J3.4, J4.4, J6.4
GPIO14: J1.6, J2.6, J5.6
GPIO15: J1.7, J2.7, J5.7
GPIO18: J3.3, J4.3, J6.3
GPIO19: J3.2, J4.2, J6.2
GPIO21: J3.6, J4.6, J6.6
GPIO22: J3.5, J4.5, J6.5
GPIO23: J3.1, J4.1, J6.1
GPIO25: J1.10, J2.10, J5.10
GPIO26: J1.9, J2.9, J5.9
GPIO27: J1.8, J2.8, J5.8
GPIO32: J3.7, J4.7, J6.7
GPIO33: J3.8, J4.8, J6.8
RESET: J3.9, J4.9, J6.9
USB: J1.3, J2.3, J5.3
VBAT: J1.1, J2.1, J5.1

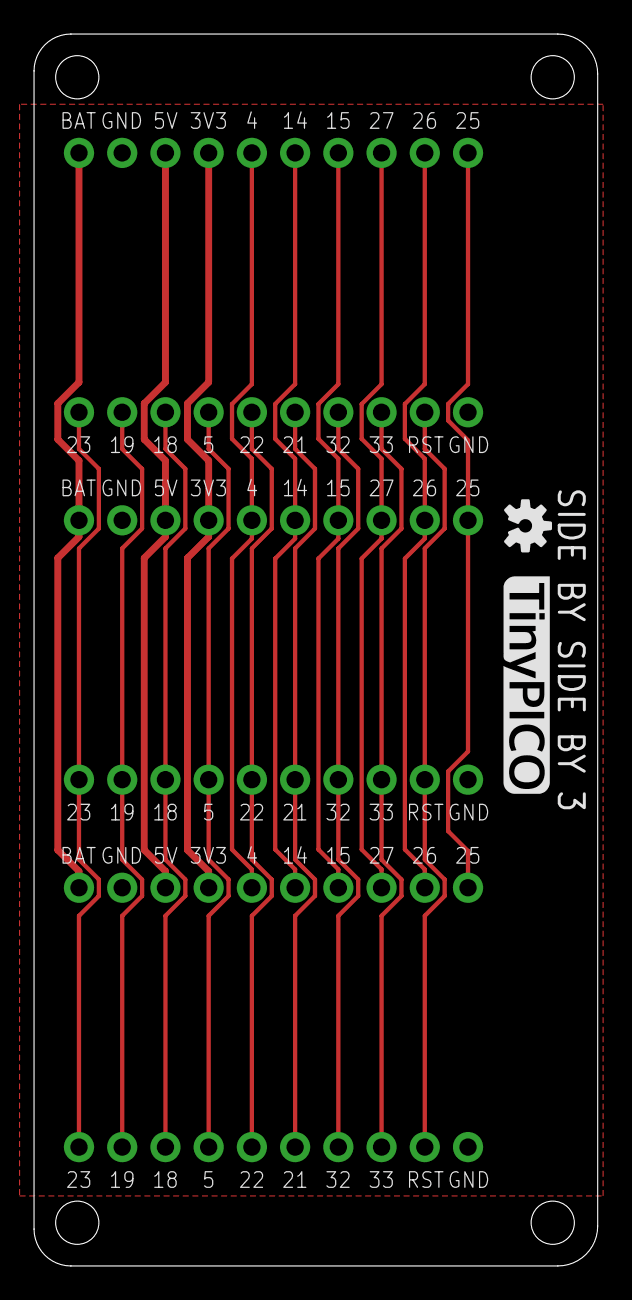
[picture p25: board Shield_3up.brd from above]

Board: 2 copper layers, 33.1 x 72.4 mm, 8 parts (1 on the bottom side), 19 nets.

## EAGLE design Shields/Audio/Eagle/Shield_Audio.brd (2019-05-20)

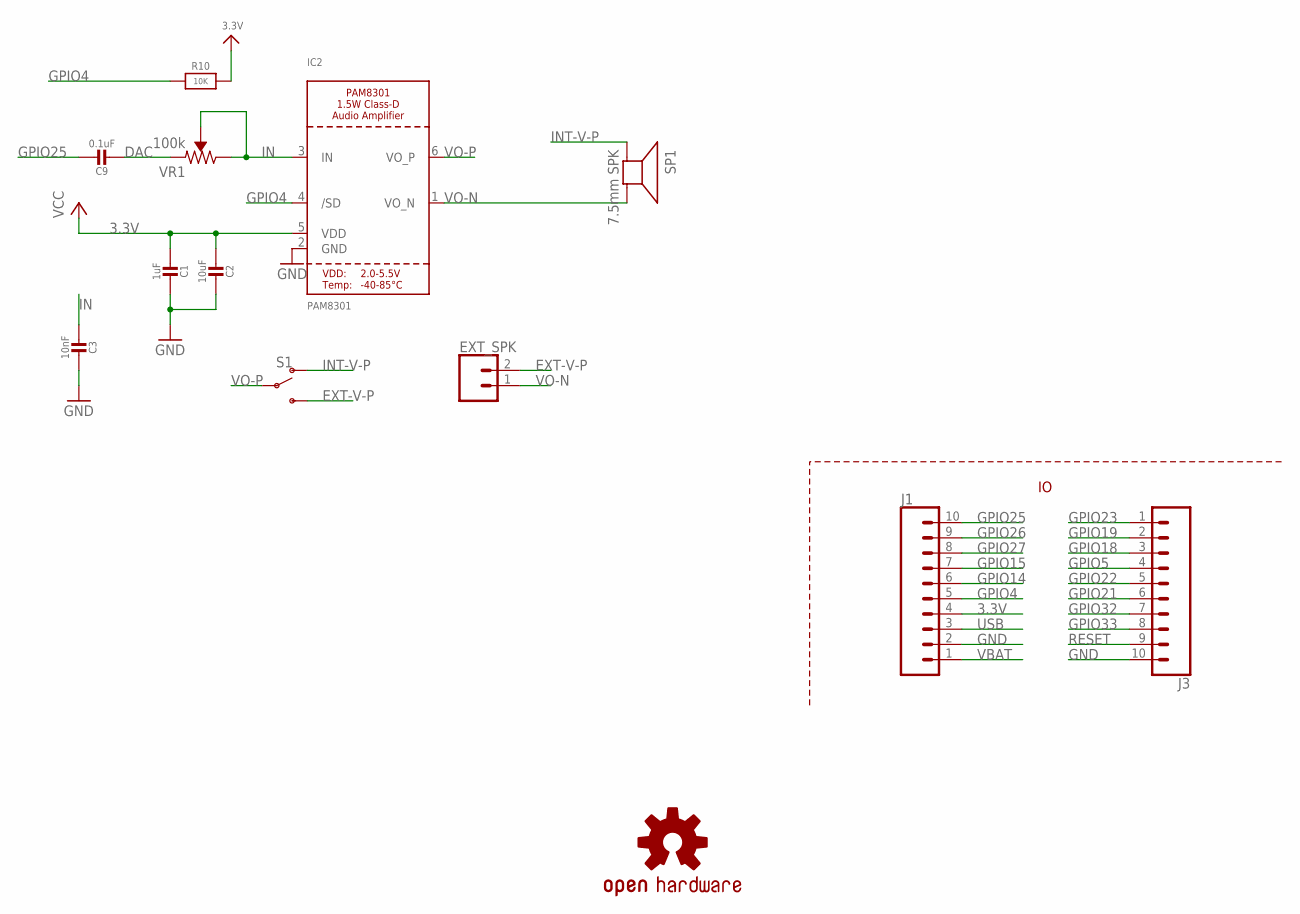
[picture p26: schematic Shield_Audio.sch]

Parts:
C1: 1uF; _0603MP
C2: 10uF; _0603MP
C3: 10nF; _0603MP
C9: 0.1uF; _0603MP
EXT_SPK: CONN_021X02_NO_SILK; 1X02_NO_SILK
IC2: PAM8301; SOT23-6
J1, J3: TINYPICO_HEADER_10NO_SILK_PTH_FEMALE; 1X10_NO_SILK
LOGO1: OSHW-LOGOS; OSHW-LOGO-S
R10: 10K; _0603MP
S1: SPARKFUN-SWITCHES_SWITCH-SPDT-SMD-RIGHT-ANGLE; SPARKFUN-SWITCHES_SWITCH_SPST_SMD_A
SP1: 7.5mm SPK; BUZZER_SMT_7.5MM
VR1: 100k; TRIMPOT-SMD-5MM

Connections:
3.3V: C1.2, C2.2, IC2.5 (VDD), J1.4, R10.2
DAC: C9.2, VR1.A (CCW)
EXT-V-P: EXT_SPK.2, S1.3 (S)
GND: C1.1, C2.1, C3.1, IC2.2 (GND), J1.2, J3.10
GPIO4: IC2.4 (/SD), J1.5, R10.1
GPIO5: J3.4
GPIO14: J1.6
GPIO15: J1.7
GPIO18: J3.3
GPIO19: J3.2
GPIO21: J3.6
GPIO22: J3.5
GPIO23: J3.1
GPIO25: C9.1, J1.10
GPIO26: J1.9
GPIO27: J1.8
GPIO32: J3.7
GPIO33: J3.8
IN: C3.2, IC2.3 (IN), VR1.B (WIPER), VR1.C (CW)
INT-V-P: S1.1 (O), SP1.+
RESET: J3.9
USB: J1.3
VBAT: J1.1
VO-N: EXT_SPK.1, IC2.1 (VO_N), SP1.-
VO-P: IC2.6 (VO_P), S1.2

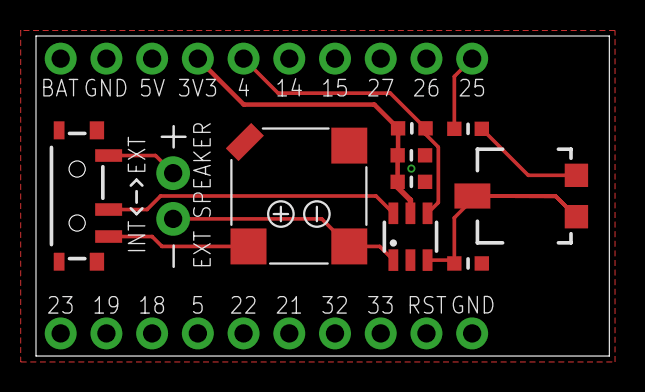
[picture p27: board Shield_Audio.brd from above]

Board: 2 copper layers, 31.9 x 17.8 mm, 13 parts (1 on the bottom side), 10 nets.

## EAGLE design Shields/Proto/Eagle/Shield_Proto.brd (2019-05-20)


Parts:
J1, J2, J3, J4: TINYPICO_HEADER_10NO_SILK_PTH_FEMALE; 1X10_NO_SILK
J7, J8, J9, J10: CONNECTORS_CONN_06NO_SILK_NO_POP; SPARKFUN-CONNECTORS_1X06_NO_SILK
J11, J12: CONN_041X04_NO_SILK; 1X04_NO_SILK
LOGO1: OSHW-LOGOS; OSHW-LOGO-S
R5, R6: 10K; _0603MP
SW2, SW4, SW5: KMR2; BTN_KMR2_4.6X2.8

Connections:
3.3V: J1.4, J2.4, J11.1, J11.2, J11.3, J11.4, SW4.B (S), SW4.B' (S1), SW5.B (S), SW5.B' (S1)
GND: J1.2, J2.2, J3.10, J4.10, J12.1, J12.2, J12.3, J12.4, R5.2, R6.2, SW2.A, SW2.A' (P1)
GPIO4: J1.5, J2.5
GPIO5: J3.4, J4.4
GPIO14: J1.6, J2.6, R5.1, SW5.A, SW5.A' (P1)
GPIO15: J1.7, J2.7, R6.1, SW4.A, SW4.A' (P1)
GPIO18: J3.3, J4.3
GPIO19: J3.2, J4.2
GPIO21: J3.6, J4.6
GPIO22: J3.5, J4.5
GPIO23: J3.1, J4.1
GPIO25: J1.10, J2.10
GPIO26: J1.9, J2.9
GPIO27: J1.8, J2.8
GPIO32: J3.7, J4.7
GPIO33: J3.8, J4.8
RESET: J3.9, J4.9, SW2.B (S), SW2.B' (S1)
USB: J1.3, J2.3
VBAT: J1.1, J2.1

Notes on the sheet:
PROTOTYPING AREA
POWER RAILS
BUTTONS


Board: 2 copper layers, 31.9 x 22.9 mm, 16 parts (1 on the bottom side), 19 nets.

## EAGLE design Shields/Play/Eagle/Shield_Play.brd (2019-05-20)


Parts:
C1, C10: 0.1µF; _0603MP
C2: 10uF; _0603MP
C3: 1uF; _0603MP
C4, C9: 0.1uF; _0603MP
IC2: PAM8301; SOT23-6
IC4: LIS3DH; LGA16_3X3MM
J1, J3: TINYPICO_HEADER_10NO_SILK_PTH_FEMALE; 1X10_NO_SILK
J2: CONN_09NO_SILK; 1X09_NO_SILK
J5: CONN_041X04_NO_SILK; 1X04_NO_SILK
JST-LIPO: LIPO; JSTPH2
LED1: LED0603_NOOUTLINE; CHIPLED_0603_NOOUTLINE
LOGO1: OSHW-LOGOS; OSHW-LOGO-S
R1, R2, R3, R5, R6, R7, R8, R9, R12: 10K; _0603MP
R4: 2K; _0603MP
R11: 47K; _0603MP
S1: SPARKFUN-SWITCHES_SWITCH-SPDT-SMD-RIGHT-ANGLE; SPARKFUN-SWITCHES_SWITCH_SPST_SMD_A
SP1: 7.5mm SPK; BUZZER_SMT_7.5MM
SW1, SW2, SW3, SW4, SW5: KMR2; BTN_KMR2_4.6X2.8
U2: ALS-PT19

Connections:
3.3V: C1.1, C2.2, C3.2, C10.1, IC2.5 (VDD), IC4.1 (VDDIO), IC4.8 (CS), IC4.14 (VDD), J1.4, J2.4, J5.2, R1.2, R3.2, R12.2, SW1.B (S), SW1.B' (S1), SW3.B (S), SW3.B' (S1), SW4.B (S), SW4.B' (S1), SW5.B (S), SW5.B' (S1), U2.C (C1)
AUDIO_IN: C4.2, IC2.3 (IN), R11.2
GND: C1.2, C2.1, C3.1, C4.1, C10.2, IC2.2 (GND), IC4.5 (GND), IC4.10 (RES(GND)), IC4.12 (GND), J1.2, J2.3, J3.10, J5.1, JST-LIPO.1, R2.1, R4.1, R5.2, R6.2, R7.2, R8.2, R9.1, SW2.A, SW2.A' (P1)
GPIO4: J1.5, J2.5, LED1.A
GPIO5: J2.6, J3.4
GPIO14: J1.6, R6.1, SW4.A, SW4.A' (P1)
GPIO15: J1.7, R5.1, SW5.A, SW5.A' (P1)
GPIO18: J2.7, J3.3
GPIO19: J2.8, J3.2
GPIO23: J2.9, J3.1
GPIO25: C9.1, J1.10
GPIO26: J1.9, R8.1, SW1.A, SW1.A' (P1)
GPIO27: J1.8, R7.1, SW3.A, SW3.A' (P1)
GPIO32: J3.7, R2.2, U2.E (E1)
GPIO33: IC4.11 (INT1), J3.8
unnamed: IC4.7 (SDO), R9.2
unnamed: LED1.C, R4.2
unnamed: C9.2, R11.1
RESET: J3.9, SW2.B (S), SW2.B' (S1)
SCL: IC4.4 (SCL), J2.1, J3.5, J5.3, R1.1
SD: IC2.4 (/SD), R12.1
SDA: IC4.6 (SDA), J2.2, J3.6, J5.4, R3.1
USB: J1.3
VBAT: J1.1, S1.1 (O)
VBAT_IN: JST-LIPO.2, S1.2
VO-N: IC2.1 (VO_N), SP1.-
VO-P: IC2.6 (VO_P), SP1.+

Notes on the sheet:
TinyPICO
LIPO CHARGE
BUTTONS
LIGHT SENSOR
3-AXIS
128x64 OLED
EXTRA IO
AMP + SPEAKER



Board: 2 copper layers, 48.3 x 43.2 mm, 34 parts (2 on the bottom side), 26 nets.

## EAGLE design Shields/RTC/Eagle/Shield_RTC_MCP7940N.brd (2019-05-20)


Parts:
C2, C4: 7pF; _0603MP
C9: 1uF; _0603MP
C10: 0.1uF; _0603MP
G1: 10MM_SM_COIN_CELL_CLIP
J2, J5: CONN_06NO_SILK_FEMALE_PTH; 1X06_NO_SILK
LOGO1: OSHW-LOGOS; OSHW-LOGO-S
R1, R2, R3: 10K; _0603MP
SJ4: SOLDERJUMPERTRACE; SPARKFUN_SJ_2S-TRACE
U$1: MCP7940N; SOIC8_150MIL
X2: 32.768; XTAL3215

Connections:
3.3V: C10.2, J2.4, R1.2, R2.2, R3.1, U$1.8 (VCC)
BAT: C9.2, G1.+@1 (+), G1.+@2 (+), U$1.3 (VBAT)
GND: C2.2, C4.2, C9.1, C10.1, G1.-, J2.2, U$1.4 (GND)
GPIO4: J2.5, SJ4.1
GPIO5: J5.4
GPIO14: J2.6
GPIO18: J5.3
GPIO19: J5.2
GPIO21: J5.6, R2.1, U$1.5 (SDA)
GPIO22: J5.5, R1.1, U$1.6 (SCL)
GPIO23: J5.1
MFP: R3.2, SJ4.2, U$1.7 (MFP)
USB: J2.3
VBAT: J2.1
X1: C4.1, U$1.1 (X1), X2.P$2
X2: C2.1, U$1.2 (X2), X2.P$1

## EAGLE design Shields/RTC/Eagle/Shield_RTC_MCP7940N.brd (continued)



Board: 2 copper layers, 24.2 x 17.8 mm, 14 parts (2 on the bottom side), 9 nets.

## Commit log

2019-06-05 Fixed PSRAM silk no back of the bopard Fixed positions of the Inductor and Cap on the matching network Updated schematic PDF
    [TinyPICO.brd, TinyPICO.sch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]
2019-08-06 Updated readme and removed TinyPICO logo from shield template
    [Shield_Empty.brd, Shield_Empty.sch]
2020-06-25 Added Colour IPS Display Shield files <- Finally!
    [Shield_Color_Display.GBL, Shield_Color_Display.GBO, Shield_Color_Display.GBS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]
2020-08-03 Added TinyPICO NANO folder with footprints for various ECAD apps
2020-09-06 Replaced Altium footprint
    this one is also compatible with Circuit Studio
2021-02-01 Added TinyPICO Nano Schematic PDF
2021-02-01 Added TinyPICO V2 PDF Schematics for Micro-B and USB-C
2021-02-16 Added TinyPICO Nano KiCAD Eschema symbol
2021-03-15 Added TinyPICO USB-C STL file and updated some readme files
2021-05-21 Added TinyPICO NANO STL & STEP Added TinyPICO USB-C STL Renamed folder to 3D files
    [TinyPICO Nano.stl]
2021-05-29 Added TinyPICO Nano KiCad 5 symbol & footprint Added TinyPICO DipTrace ASCII files (thanks airheadbit) Cleaned up folder structure
2022-04-13 Added STL case files for Explorer Shield & Schematic
    [Explorer_Case_Slim.stl]

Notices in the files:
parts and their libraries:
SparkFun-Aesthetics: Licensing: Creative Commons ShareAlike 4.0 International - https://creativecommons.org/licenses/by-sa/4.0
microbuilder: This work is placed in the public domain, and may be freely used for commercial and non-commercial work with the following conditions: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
